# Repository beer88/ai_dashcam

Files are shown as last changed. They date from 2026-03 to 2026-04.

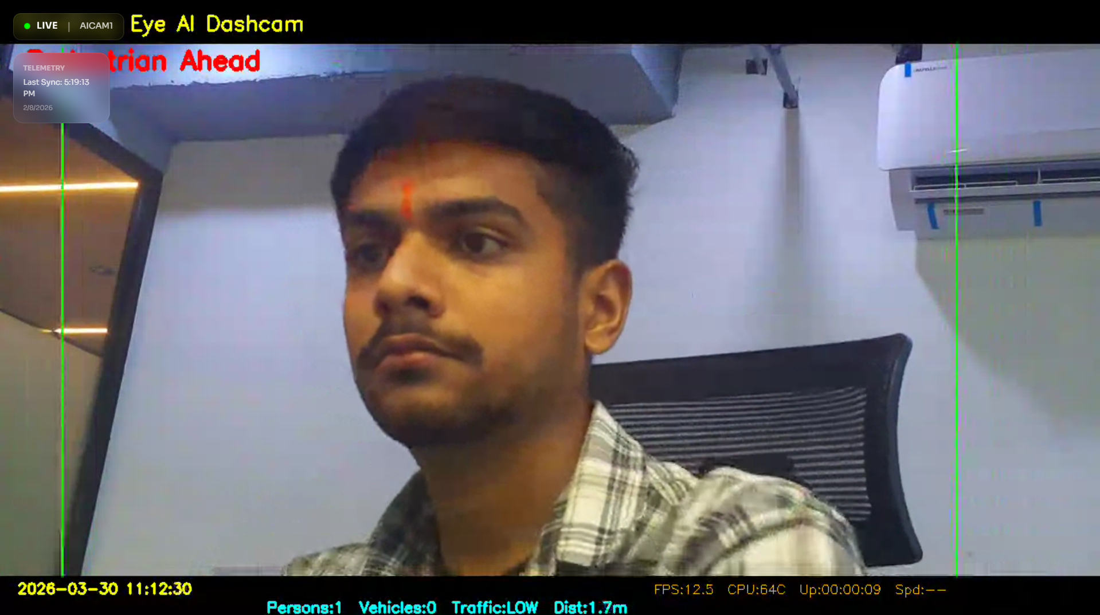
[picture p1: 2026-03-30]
docs/Screenshot 2026-03-30 111230.png

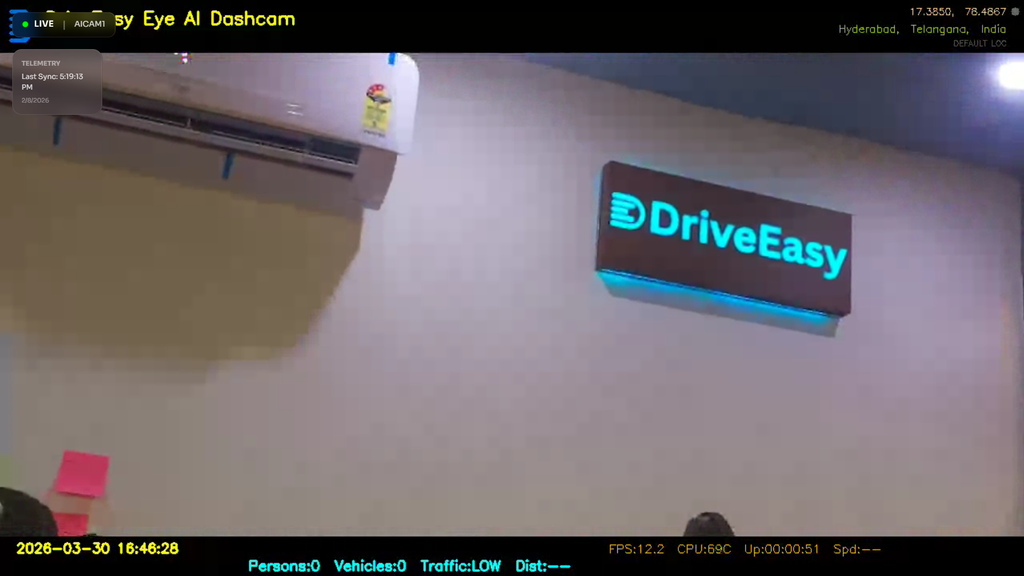
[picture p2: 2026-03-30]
docs/Screenshot 2026-03-30 164631.png

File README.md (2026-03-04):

# AI Dashcam System

An AI-powered Dashcam system built using Raspberry Pi that provides real-time video recording, intelligent event detection, and vehicle monitoring. The system integrates hardware and software components to enhance driving safety and provide smart surveillance capabilities.

## Features

- Real-time video recording using Raspberry Pi Camera
- AI-based object detection
- Automatic event recording
- GPS tracking support
- GSM/4G connectivity for remote monitoring
- Data storage on SD card
- Easy integration with vehicle systems

## Hardware Components

- Raspberry Pi 4
- Raspberry Pi Camera Module
- GPS Module
- GSM/4G Module
- Micro SD Card
- Power Supply Module
- Vehicle Mount

## Software Requirements

- Python 3
- OpenCV
- TensorFlow / PyTorch
- Raspberry Pi OS
- Git

## Project Structure

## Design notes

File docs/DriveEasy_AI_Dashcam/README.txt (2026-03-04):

DriveEasy AI Dashcam - KiCad Project Template

Project Name: DriveEasy_AI_Dashcam

This folder contains structured schematic pages ready for hierarchical design.

Pages:
- 00_System_Overview.kicad_sch
- 01_Power_Supply.kicad_sch
- 02_Raspberry_Pi_Core.kicad_sch
- 03_CSI_Camera_Interface.kicad_sch
- 04_LTE_Module.kicad_sch
- 05_Audio_Microphone.kicad_sch
- 06_Storage.kicad_sch
- 07_User_Interface.kicad_sch
- 08_External_Connectors.kicad_sch

Next Steps:
1. Open KiCad.
2. Open DriveEasy_AI_Dashcam.kicad_pro.
3. Create hierarchical sheet links inside 00_System_Overview.
4. Populate each schematic page.
5. Assign footprints.
6. Generate PCB layout.

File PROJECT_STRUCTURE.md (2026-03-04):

# Project Structure

hardware/
Contains all hardware related files such as schematics and PCB designs.

firmware/
Contains Raspberry Pi firmware and low level code.

software/
Contains AI models and processing scripts.

docs/
Contains project documentation and reports.

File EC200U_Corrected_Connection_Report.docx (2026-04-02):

EC200U-CN MODULE

CORRECTED COMPLETE CONNECTION REPORT

Schematic: EC200UCNAA-N05-SGNSA | KiCad 9.0.6 | All Pins | 14 Errors Fixed

✘ CRITICAL ERROR: 5 CRITICAL ERRORS FOUND IN YOUR SCHEMATIC. Fix all red items before ordering PCBs.

# Section 1 — All Errors Found in Your EC200U Schematic

The following errors were identified by comparing your uploaded schematic (EC200UCNAA-N05-SGNSA symbol) against the Quectel EC200U Series Hardware Design specification. Red = Critical (device won't work or will be damaged). Orange = High (instability or missing connection).

# | EC200U Pin | Current Wrong Connection | Correct Connection | Severity

1 | Pin 64 — MAIN_DTR | UART2_TX net connected here | UART2_TX must go to MAIN_RXD (pin 62). DTR is a modem control line, NOT data! | 🔴 CRITICAL
2 | Pin 62 — MAIN_RXD | UART2_RX net connected here | UART2_RX must come FROM MAIN_TXD (pin 63). MCU_RX ← Module_TX is correct direction. | 🔴 CRITICAL
3 | Pin 63 — MAIN_TXD | No connection (NC) — floating! | Must connect to UART2_RX (ESP32 IO16). Module transmits → ESP32 receives. | 🔴 CRITICAL
4 | Pin 50 — VBAT_BB | Connected to VCC_5V (5.0V) | Must be 3.4V–4.3V ONLY. Add 4.2V LDO (AMS1117-4.2) between 5V and VBAT_BB. | 🔴 CRITICAL
5 | Pin 57 — VBAT_RF | Connected to VCC_5V (5.0V) | Must be 3.4V–4.3V. Connect same 4.2V rail as VBAT_BB. VBAT_RF = PA power. | 🔴 CRITICAL
6 | Pin 128 — VDD_EXT | Connected to VCC_1V8 rail | VDD_EXT is an OUTPUT from EC200U (module provides 1.8V). Do NOT connect to LDO output. Use VDD_EXT to power other 1.8V peripherals, or leave NC. | 🟠 HIGH
7 | Pin 64 — MAIN_DTR | UART2_TX incorrectly here | MAIN_DTR should connect to ESP32 IO33 (DTR signal for sleep control). Leave NC if sleep not needed. | 🟠 HIGH
8 | Pin 61 — MAIN_RTS | Floating / NC | Tie to GND (3.3V logic) to disable hardware flow control, OR connect to ESP32 GPIO if HW flow control is used. | 🟡 MEDIUM
9 | Pin 19 — STATUS | Net label: NMODULE_STATUS | In previous report label was MODULE_STATUS. Rename net in KiCad to MODULE_STATUS and connect to ESP32 IO35 (input). HIGH = module ON. | 🟡 MEDIUM
10 | Pin 23 — SIM_DET | NC / floating | Connect to SIM card holder card-detect switch pin. Add 47kΩ pull-up to VDD_EXT (1.8V). LOW = SIM inserted. | 🟡 MEDIUM
11 | GRF_C1 / GRF_C2 | No 100nF caps visible | REQUIRED: Add 100nF capacitor from each GRF_C1 (pin 143) and GRF_C2 (pin 139) to GND. Quectel hardware design mandatory. | 🟠 HIGH
12 | Pin 1 — WAKEUP_IN | NC / floating | Pull HIGH to VDD_EXT (1.8V) via 47kΩ to keep module awake. Or connect to ESP32 GPIO for controlled wake. | 🟡 MEDIUM
13 | Pin 47 — ANT_GNSS | No SMA connection visible on this pin | Must connect to J3 SMA_Edge_SMD via 50Ω microstrip trace. This is the GNSS antenna port. | 🟠 HIGH
14 | Pin 48 — ANT_MAIN | No SMA connection visible on this pin | Must connect to J2 SMA_Edge_SMD via 50Ω microstrip trace. This is the LTE antenna port. | 🟠 HIGH

✘ CRITICAL ERROR: The 3 UART errors (#1, #2, #3) mean: EC200U will NEVER respond to AT commands, GPS data will NEVER arrive. The design will appear completely dead even if power is correct.

✘ CRITICAL ERROR: VBAT errors (#4, #5): Powering EC200U at 5V will destroy the module permanently. EC200U VBAT max = 4.3V absolute maximum.

⚠ WARNING: VDD_EXT error (#6): Connecting two voltage sources together (LDO output + module output) on the same net will cause one to fight the other — resulting in excess current, heating, and possible damage.

# Section 2 — UART Connection Correction (Most Important Fix)

## 2.1 What Is Wrong in Your Schematic:

- UART2_TX net is connected to EC200U pin 64 (MAIN_DTR). MAIN_DTR is a modem handshaking control line (Data Terminal Ready), NOT a data pin. Your ESP32 AT commands go nowhere.
- UART2_RX net is connected to EC200U pin 62 (MAIN_RXD). MAIN_RXD is the pin where EC200U RECEIVES data from you — not transmits. So ESP32 RX is listening to the wrong line.
- EC200U pin 63 (MAIN_TXD) — the pin that actually sends AT responses back — has NO CONNECTION at all. This is why the module will seem completely silent.

## 2.2 Correct UART Connections — Full Table:

UART Channel | ESP32 Pin | ESP32 Function | Wire Direction | EC200U Pin # | EC200U Signal | Baud Rate | Net Label
UART0 (Debug) | IO1 (TXD0) | TX — ESP32 transmits | ESP32 → CP2102N RXD | — | CP2102N RXD | 115200 | DEBUG_TX
UART0 (Debug) | IO3 (RXD0) | RX — ESP32 receives | CP2102N TXD → ESP32 | — | CP2102N TXD | 115200 | DEBUG_RX
UART2 (EC200U MAIN) — CORRECTED | IO17 | TX — ESP32 transmits | ESP32 IO17 → EC200U pin 62 (MAIN_RXD) | Pin 62 — MAIN_RXD | MAIN_RXD (module receives) | 115200 | UART2_TX
UART2 (EC200U MAIN) — CORRECTED | IO16 | RX — ESP32 receives | EC200U pin 63 (MAIN_TXD) → ESP32 IO16 | Pin 63 — MAIN_TXD | MAIN_TXD (module transmits) | 115200 | UART2_RX
DTR (was wrongly UART2_TX) | IO33 | OUT — sleep control | ESP32 IO33 → EC200U pin 64 (MAIN_DTR) | Pin 64 — MAIN_DTR | DTR sleep control signal | — | DTR
UART1 (EC200U GNSS) | IO13 | RX — ESP32 receives | EC200U GNSS_TXD → ESP32 IO13 | GNSS_TXD | GNSS transmits NMEA | 9600 | GNSS_DATA
UART1 (EC200U GNSS) | IO12 | TX — ESP32 transmits | ESP32 IO12 → EC200U GNSS_RXD | GNSS_RXD | GNSS receives config | 9600 | GNSS_CMD

✔ Golden rule: MCU_TX → Module_RXD (module receives your commands). MCU_RX ← Module_TXD (module sends back responses). TX→RX, RX←TX — always cross-connect.

## 2.3 Step-by-Step Fix in KiCad:

- Delete the UART2_TX net label from pin 64 (MAIN_DTR)
- Add net label UART2_TX on pin 62 (MAIN_RXD) — ESP32 IO17 sends commands here
- Add net label UART2_RX on pin 63 (MAIN_TXD) — EC200U sends responses here → ESP32 IO16 receives
- On pin 64 (MAIN_DTR), add net label DTR — connect this to ESP32 IO33 for sleep control
- In ESP32 schematic: verify IO17 = UART2_TX, IO16 = UART2_RX (confirm both match)

# Section 3 — Power Supply Correction

## 3.1 EC200U VBAT Voltage — Critical Fix

The EC200U-CN VBAT (pins 50 = VBAT_BB, 57 = VBAT_RF) operating voltage is 3.4V to 4.3V. Your schematic connects both VBAT pins to VCC_5V (5.0V). This exceeds the absolute maximum rating and WILL permanently damage or destroy the module.

Pin | Signal | Wrong | Correct | Add Component | KiCad Symbol
50 | VBAT_BB | VCC_5V (5.0V) — DESTROYS MODULE | VBAT_4V2 — Output of new 4.2V LDO. Connect through ferrite bead + 100µF cap. | Add: AMS1117-4.2 or HT7342 LDO (SOT-223) | Regulator_Linear:AMS1117-4.2
57 | VBAT_RF | VCC_5V (5.0V) — DESTROYS MODULE | VBAT_4V2 — Same 4.2V LDO output as VBAT_BB. Both pins share same VBAT rail. | Same 4.2V LDO as above | Same component
128 | VDD_EXT | Connected TO VCC_1V8 — OUTPUT conflict | VDD_EXT is OUTPUT from EC200U (1.8V). Remove VCC_1V8 connection. Use VDD_EXT to power PWRKEY/RESET pull-ups instead. | Remove connection to AMS1117-1.8 output. Use VDD_EXT as supply for pull-ups. | Net label: VDD_EXT_OUT
AMS1117-1.8 usage | VCC_1V8 (if kept) | Conflict with VDD_EXT | If AMS1117-1.8 is kept for other purposes, isolate from VDD_EXT pin. Or remove AMS1117-1.8 entirely and use EC200U's VDD_EXT for 1.8V needs. | Optional: Remove AMS1117-1.8 to simplify BOM | Remove if unused

## 3.2 New Power Circuit — Add AMS1117-4.2 LDO:

Component | KiCad Symbol | Connection | Notes
AMS1117-4.2 | Regulator_Linear:AMS1117-4.2 (SOT-223) | VI = VCC_5V, VO = VBAT_4V2, GND = PGND | Provides 4.2V @ 1A. Max EC200U current is ~2A peak. For 2A use LP38501-ADJ.
100µF Cap | Device:C (Electrolytic) | Between VBAT_4V2 and GND — close to AMS1117 output | Handles EC200U 4G TX peak current bursts (up to 2A, ~2ms).
10µF Cap | Device:C (0805 Ceramic) | Between VBAT_4V2 and GND — close to EC200U VBAT pins | Ceramic for fast transient response.
100nF Cap | Device:C (0402 Ceramic) | Between VBAT_4V2 and GND — right at each VBAT pin | High-frequency decoupling. Place within 2mm of pin.
Ferrite Bead | Device:Ferrite_Bead (0805) | In series on VBAT_4V2 line before EC200U | 220Ω@100MHz. EMI isolation between power supply and RF module.

## 3.3 VDD_EXT Pin (128) — Correct Usage:

- VDD_EXT is an OUTPUT from the EC200U module. It provides 1.8V at up to 50mA for external use.
- Disconnect it from VCC_1V8 rail (AMS1117-1.8 output). They will conflict.
- Use VDD_EXT to supply: PWRKEY pull-up resistor (10kΩ from VDD_EXT to PWRKEY), RESET pull-up (10kΩ from VDD_EXT to RESET), USIM card power is provided directly from EC200U internally.
- If you still need 1.8V elsewhere on the board, keep AMS1117-1.8 but isolate it from VDD_EXT completely.

# Section 4 — EC200U Complete Pin Map (All Pins — Verified)

This is the definitive pin-by-pin table based on the exact EC200UCNAA-N05-SGNSA symbol visible in your uploaded schematic. Every pin is documented with its correct connection. Use this as your ground truth when fixing the schematic.

Pin # | Pin Name | Current Schematic Connection | CORRECT Connection | Net Label | Status

POWER PINS
50 | VBAT_BB | VCC_5V → WRONG (5V) | 4.2V LDO output (add AMS1117-4.2 between VCC_5V and this pin) | VBAT_4V2 | ❌ FIX REQUIRED
57 | VBAT_RF | VCC_5V → WRONG (5V) | Same 4.2V LDO rail as VBAT_BB (share same rail) | VBAT_4V2 | ❌ FIX REQUIRED
128 | VDD_EXT | Connected TO VCC_1V8 — CONFLICT | VDD_EXT is an OUTPUT (EC200U provides 1.8V here). Use VDD_EXT to power other 1.8V devices OR leave NC. NEVER connect to LDO output. | VDD_EXT_OUT | ⚠ FIX REQUIRED
8 / GND_1 | GND | → GND | → PGND copper pour | GND | ✔ Correct
85 / GND_2 | GND | → GND | → PGND copper pour | GND | ✔ Correct
101 / GND_3 | GND | → GND | → PGND copper pour | GND | ✔ Correct

CONTROL PINS
21 | PWRKEY | MODULE_PWR ← ESP32 IO26 ✔ | Correct. Add 10kΩ pull-up from PWRKEY to VDD_EXT (1.8V) to keep HIGH when GPIO is floating. | MODULE_PWR | ✔ Correct
20 | RESET | MODULE_RESET ← ESP32 IO27 ✔ | Correct. Add 10kΩ pull-up from RESET to VDD_EXT (1.8V) to keep deasserted (HIGH). | MODULE_RESET | ✔ Correct
19 | STATUS | Net = NMODULE_STATUS (name mismatch vs ESP32 schematic = MODULE_STATUS) | Rename net to MODULE_STATUS for consistency. Connect to ESP32 IO35 input. HIGH = module ON. | MODULE_STATUS | ⚠ Rename Net
3 | SLEEP_IND | NC — floating | Optional: connect to ESP32 GPIO (input). LOW = module in sleep. Leave NC if not monitoring sleep state. | SLEEP_IND | NC — Optional
2 | AP_READY | NC — floating | Optional handshake. Can tie HIGH to VDD_EXT (1.8V) via 47kΩ or leave NC. | AP_READY | NC — OK
190 | ISINK | NC | LED current sink (if module has LED). Leave NC. | — | NC
1 | WAKEUP_IN | NC — floating (dangerous) | REQUIRED: Pull HIGH via 47kΩ to VDD_EXT (1.8V). If left floating, module may not wake properly. | VDD_EXT via 47kΩ | ⚠ Add pull-up
4 | V_DISABLE | NC | Pull HIGH to VDD_EXT (1.8V) via 10kΩ. HIGH = module RF enabled. LOW disables RF. | VDD_EXT via 10kΩ | ⚠ Add pull-up
23 | SIM_DET | NC — not connected to SIM holder | Connect to SIM card holder card-detect pin. 47kΩ pull-up to VDD_EXT. LOW = SIM inserted. | USIM_DET | ⚠ Connect to SIM
5 | NET_MODE | NC | Optional LED indicator for network mode. 10kΩ series to LED → GND. Or leave NC. | — | NC — Optional
6 | NET_STATUS | NC | Optional LED indicator for network registration. Drives LED to show 2G/4G connection status. | — | NC — Optional
439 | BY_EN | NC | Bypass enable — module internal. Leave NC. | — | NC

MAIN UART — AT Commands & 4G Data (CRITICAL CORRECTIONS BELOW)
64 | MAIN_DTR | UART2_TX connected here — WRONG! DTR ≠ UART data | MAIN_DTR = modem control signal (sleep control). Connect to ESP32 IO33 (DTR). If sleep not used, leave NC or pull LOW. | DTR | ❌ WRONG — Move UART2_TX to pin 62
62 | MAIN_RXD | UART2_RX connected here — WRONG! RXD = EC200U receives | MAIN_RXD = EC200U receives data. Must connect to ESP32 UART2_TX (IO17). NOT to ESP32 RX pin. | UART2_TX (from ESP32 IO17) | ❌ WRONG — Change to UART2_TX
63 | MAIN_TXD | NC — Floating! No connection | MAIN_TXD = EC200U transmits data. MUST connect to ESP32 UART2_RX (IO16). Critical — ESP32 receives all AT responses here. | UART2_RX (to ESP32 IO16) | ❌ FIX — Must be connected!
61 | MAIN_RTS | NC — floating | Tie to GND to disable hardware flow control (most common). OR connect to ESP32 CTS if using flow control. | GND (tie) | ⚠ Tie to GND
65 | MAIN_DCD | NC | Data Carrier Detect — output from module. Not needed for AT command usage. Leave NC. | — | NC — OK
66 | MAIN_RI | NC | Ring Indicator — output, LOW on incoming call/SMS. Connect to ESP32 IO34 (input) for wake-up, or leave NC. | RING_IND → IO34 | Optional

GNSS UART — GPS/NMEA Data
47 | ANT_GNSS | No net/connection shown in schematic! | MUST connect to J3 (SMA_Edge_SMD) via 50Ω controlled impedance microstrip trace. GNSS antenna is mandatory. | GNSS_ANT → J3 | ⚠ Connect to J3 SMA
Implied | GNSS_TXD | GNSS_DATA → ESP32 IO13 (schematic shows this) | GNSS_TXD (EC200U transmits NMEA) → ESP32 IO13 (UART1 RX). Correct direction. | GNSS_DATA | ✔ Correct
Implied | GNSS_RXD | GNSS_CMD → ESP32 IO12 (schematic shows this) | GNSS_RXD (EC200U GNSS receives config) ← ESP32 IO12 (UART1 TX). Correct direction. | GNSS_CMD | ✔ Correct

LTE ANTENNA
48 | ANT_MAIN | No net/connection shown in schematic! | MUST connect to J2 (SMA_Edge_SMD) via 50Ω controlled impedance microstrip trace. LTE antenna is mandatory. | LTE_ANT → J2 | ⚠ Connect to J2 SMA
35 | ANT_BT/WIFI_SCAN | NC | Not used. Leave NC in this design (no BT/WiFi functionality). | — | NC — OK

SIM CARD (USIM) — Connects to J1 SIM Card Holder
9 | USIM_VDD | → SIM holder VCC pin (J1 pin 1) | EC200U supplies 1.8V or 3V to SIM. Add 47pF decoupling to GND on SIM side. | USIM_VCC | ✔ Connect to SIM
13 | USIM_DET | NC — not connected | Connect to SIM holder card-detect switch. 47kΩ pull-up to VDD_EXT. LOW when SIM inserted. | USIM_DET | ⚠ Connect
15 | USIM_DATA | → SIM holder I/O pin (J1 pin 7) | Bidirectional data. Add 22Ω series resistor + 47pF to GND for ESD protection. | USIM_DATA | ✔ Connect to SIM
16 | USIM_CLK | → SIM holder CLK pin (J1 pin 3) | Clock output to SIM. Add 22Ω series + 47pF to GND. | USIM_CLK | ✔ Connect to SIM
17 | USIM_RST | → SIM holder RST pin (J1 pin 2) | Active LOW reset to SIM. Add 22Ω series. | USIM_RST | ✔ Connect to SIM
18 | USIM_GND | → SIM holder GND pin (J1 pin 5) | Ground for SIM card. Must connect. | GND | ✔ Connect to SIM

USB 2.0 (EC200U Internal — Optional)
71 | USB_VBUS | NC | 5V input if using EC200U USB. NC if using UART-only mode (AT over UART). Leave NC. | — | NC — Using UART
115 | USB_BOOT | NC | Tie to GND for normal operation. HIGH only for EC200U USB firmware update mode. | GND (tie) | ⚠ Tie to GND
69 | USB_DN | NC | USB D-. Leave NC if not using USB port. | — | NC — OK
68 | USB_DP | NC | USB D+. Leave NC if not using USB port. | — | NC — OK

I2C Port (EC200U Internal — NC in this design)
42 | I2C_SDA | NC | EC200U's own I2C port. NOT the ESP32 I2C bus. Leave NC — ESP32 manages all I2C peripherals directly. | — | NC — OK
41 | I2C_SCL | NC | EC200U's own I2C clock. Leave NC. | — | NC — OK
142 | I2C2_SDA | NC | Second I2C port on EC200U. Leave NC. | — | NC — OK
154 | I2C2_SCL | NC | Second I2C clock. Leave NC. | — | NC — OK

ADC Pins (Analog Inputs)
44 | ARCD (ADC0) | NC | Can use for battery voltage monitoring. Connect through 100kΩ/10kΩ divider from VIN_12V. Or NC. | — | NC — Optional
43 | ADC1 | NC | Spare ADC. Leave NC. | — | NC
52 | ADC2 | NC | Spare ADC. Leave NC. | — | NC

AUX UART (Secondary AT Port — NC in this design)
137 | AUX_RXD | NC | Tie HIGH via 47kΩ to VDD_EXT (idle HIGH for UART RX). NC if not using secondary AT port. | VDD_EXT 47kΩ or NC | NC — OK
138 | AUX_TXD | NC | Leave NC if not using secondary UART. Can connect to logic analyzer test point. | — | NC — OK
11 | DBG_RXD | NC | EC200U internal debug UART RX. Leave NC in production. | — | NC
12 | DBG_TXD | NC | EC200U debug output. NC in production (can add test point during development). | — | NC

Keypad Interface (NC in this design)
78 | KEYIN1 | NC | Not used. Leave NC. | — | NC
79 | KEYIN2 | NC | Not used. Leave NC. | — | NC
80 | KEYIN3 | NC | Not used. Leave NC. | — | NC
83 | KEYOUT1 | NC | Not used. Leave NC. | — | NC
84 | KEYOUT2 | NC | Not used. Leave NC. | — | NC
113 | KEYOUT3 | NC | Not used. Leave NC. | — | NC
111 | KEYOUT4 | NC | Not used. Leave NC. | — | NC

Audio / Microphone (NC in this design)
76 | MIC_P | NC | Microphone positive. Not needed for OBD tracker. Leave NC. | — | NC
77 | MIC_N | NC | Microphone negative. Not needed. Leave NC. | — | NC
73 | LOUD5PK_P | NC | Speaker output positive. Not used. Leave NC. | — | NC
74 | LOUD5PK_N | NC | Speaker output negative. Not used. Leave NC. | — | NC

PCM Audio Interface (NC in this design)
27 | PCM_CLK | NC | PCM clock. Not used. Leave NC. | — | NC
24 | PCM_DIN | NC | PCM data in. Not used. Leave NC. | — | NC
25 | PCM_SYNC | NC | PCM sync. Not used. Leave NC. | — | NC
26 | PCM_DOUT | NC | PCM data out. Not used. Leave NC. | — | NC

LCD Interface (NC in this design)
121 | LCD_SEL | NC | LCD select. Not used. | — | NC
119 | LCD_FMARK | NC | LCD frame mark. Not used. | — | NC
122 | LCD_CS | NC | LCD chip select. Not used. | — | NC
120 | LCD_RSTB | NC | LCD reset. Not used. | — | NC
124 | LCD_SDC | NC | LCD serial data clock. Not used. | — | NC
123 | LCD_SI/O | NC | LCD serial I/O. Not used. | — | NC

WLAN / WiFi (NC — not applicable for EC200U standard variant)
136 | VLAN_EN | NC | Pull LOW or leave NC. EC200U standard variant has no WiFi. | GND | Pull LOW
127 | WLAN_PWR_EN | NC | Leave NC. | — | NC
118 | WLAN_SLP_CLK | NC | Leave NC. | — | NC
135 | WLAN_WAKE | NC | Leave NC. | — | NC

SPI Flash Port (EC200U Internal — NC)
50 area | SPL_CLK | NC | SPI flash clock — internal to module. Leave NC. | — | NC
~37 | SPL_CS | NC | SPI flash chip select — internal. Leave NC. | — | NC
~38 | SPL_DOUT | NC | SPI flash data out — internal. Leave NC. | — | NC
~39 | SPL_DIN | NC | SPI flash data in — internal. Leave NC. | — | NC

SDIO1 (External SD card — NC in this design)
34 | SDIO1_VDD | NC | SDIO card power. NC if no SD card. | — | NC
31 | SDIO1_DATA0 | NC | Leave NC. | — | NC
30 | SDIO1_DATA1 | NC | Leave NC. | — | NC
29 | SDIO1_DATA2 | NC | Leave NC. | — | NC
28 | SDIO1_DATA3 | NC | Leave NC. | — | NC
33 | SDIO1_CMD | NC | Leave NC. | — | NC
32 | SDIO1_CLK | NC | Leave NC. | — | NC

SDIO2 (Second SDIO — NC in this design)
132 | SDIO2_DATA0 | NC | Leave NC. | — | NC
134 | SDIO2_DATA1 | NC | Leave NC. | — | NC
130 | SDIO2_DATA2 | NC | Leave NC. | — | NC
129 | SDIO2_DATA3 | NC | Leave NC. | — | NC
131 | SDIO2_CMD | NC | Leave NC. | — | NC
133 | SDIO2_CLK | NC | Leave NC. | — | NC

RF Decoupling Pins — MANDATORY
143 | GRFC1 | No 100nF cap visible in schematic | MANDATORY: Add 100nF capacitor from pin 143 to GND as close as possible to module. | GND via 100nF | ⚠ ADD CAP
139 | GRFC2 | No 100nF cap visible in schematic | MANDATORY: Add 100nF capacitor from pin 139 to GND as close as possible to module. | GND via 100nF | ⚠ ADD CAP

General Purpose IO
126 | GPIO1 | NC | Optional GPIO — can drive an LED (10kΩ series) or leave NC. | — | NC — Optional

Reserved Pins — DO NOT CONNECT
18 area | RESERVED | Must be NC | NEVER connect reserved pins to any net — this can permanently damage the module. | NC — MANDATORY | ❌ Must stay NC

# Section 5 — Antenna Connection Details

## 5.1 LTE Main Antenna (ANT_MAIN — Pin 48 → J2)

The LTE antenna trace is one of the most critical PCB layout elements. An incorrect trace impedance will significantly reduce signal strength and may cause regulatory non-compliance.

Item | Specification
EC200U Pin | Pin 48 — ANT_MAIN
Connector | J2 — SMA_Edge_SMD (SMA edge-mount at board edge)
Trace Type | 50Ω controlled impedance microstrip on 4-layer board
Trace Width | ~1.8mm on standard FR4, 4-layer, 35µm copper, L1-to-L2 reference (calculate with AppCAD or Saturn PCB Toolkit)
Trace Length | Keep as short as possible. Route on top layer with unbroken ground plane on L2 below.
Ground Stitching | Via fence every 3mm along both sides of RF trace. Keep-out zone 3mm from all other traces.
RF Matching (R1+C2) | Optional pi-network between ANT_MAIN and SMA center pin. For dev boards: 0Ω series (R1) + 100nF shunt (C2). For production: tune with VNA.
Antenna Type | External LTE rubber duck or PCB antenna, 700MHz–2600MHz, 50Ω

## 5.2 GNSS Antenna (ANT_GNSS — Pin 47 → J3)

Item | Specification
EC200U Pin | Pin 47 — ANT_GNSS
Connector | J3 — SMA_Edge_SMD (SMA edge-mount at board edge)
Trace Type | 50Ω controlled impedance microstrip
Active vs Passive Antenna | Active antenna (built-in LNA): requires DC bias on SMA center pin (3.3V through ferrite bead 10Ω@100MHz + 100nF series capacitor). Passive antenna: no bias needed.
Bias-T for Active | Ferrite bead (100nF cap block) on signal path + 3.3V feed through ferrite on center pin. Add to schematic between J3 and ANT_GNSS net.
Cold Start Fix Time | ~30s (open sky, GNSS powered). Keep antenna away from metal objects.

# Section 6 — SIM Card Full Connection

EC200U Pin | Signal | SIM Holder Pin | Series R | Notes
9 | USIM_VDD | Pin C1 (VCC) | 0Ω (direct) | EC200U auto-detects 1.8V or 3V SIM. Add 47pF to GND on SIM side.
17 | USIM_RST | Pin C2 (RST) | 22Ω | Active LOW. 47pF to GND near SIM holder.
16 | USIM_CLK | Pin C3 (CLK) | 22Ω | Clock. 47pF to GND near SIM holder.
Pin C4 (reserved) | — | NC | NC | Leave floating — not connected to EC200U.
SIM GND | GND | Pin C5 (GND) | 0Ω | Connect to DGND plane.
Pin C6 (VPP) | — | NC | NC | Not used for nano/micro SIM — leave NC.
15 | USIM_DATA | Pin C7 (I/O) | 22Ω | Bidirectional. 47pF to GND near SIM.
23 | USIM_DET | Detect switch | — | 47kΩ pull-up to VDD_EXT. LOW = SIM card inserted.
SIM shield pins | Metal shell | Holder GND tabs | 0Ω | Connect SIM holder metal shell to DGND — important for ESD/EMC.

⚠ WARNING: Add ESD protection on SIM lines. Recommended: PRTR5V0U2X (NXP, SC-74) on USIM_DATA and USIM_CLK. Place within 10mm of SIM holder.

# Section 7 — Module Power-On Sequence (Firmware Reference)

The EC200U-CN requires a specific power-on sequence. If this is not followed in firmware, the module will not respond.

Step | Action | Signal / GPIO | Timing
1 | Apply VBAT_4V2 power | VBAT_BB + VBAT_RF = 4.2V | Power stable before PWRKEY pulse
2 | Confirm STATUS = LOW | ESP32 IO35 reads LOW | Module is off. STATUS=LOW means module not yet running.
3 | Assert PWRKEY LOW | ESP32 IO26 → drive LOW (0V) | Hold LOW for minimum 500ms (recommend 600ms)
4 | Release PWRKEY HIGH | ESP32 IO26 → release HIGH (via 10kΩ pull-up) | Release after 600ms. Module begins boot.
5 | Wait for STATUS=HIGH | ESP32 IO35 reads HIGH | Wait up to 5 seconds. HIGH = module boot complete.
6 | Wait for 'RDY' or 'APP_RDY' | UART2_RX (IO16) from MAIN_TXD (pin 63) | Module sends 'RDY\r\n' when ready for AT commands.
7 | Send AT command | UART2_TX (IO17) → pin 62 (MAIN_RXD) | Send 'AT\r\n'. Should receive 'OK\r\n' back on IO16.
8 | Normal operation | All UART/GNSS active | Begin AT+CREG?, AT+CGNSPWR=1, etc.

ℹ Power-off sequence: Assert PWRKEY LOW for minimum 2500ms (2.5 seconds), then release. Wait for STATUS=LOW. Do NOT remove VBAT while module is running — may corrupt internal flash.

# Section 8 — Net Label Consistency Check (ESP32 ↔ EC200U)

Signal Function | ESP32 GPIO | ESP32 Net Label | EC200U Pin | EC200U Net Label (Correct)
4G UART TX | IO17 | UART2_TX | Pin 62 MAIN_RXD | UART2_TX (match exactly)
4G UART RX | IO16 | UART2_RX | Pin 63 MAIN_TXD | UART2_RX (match exactly)
Module Power Key | IO26 | MODULE_PWR | Pin 21 PWRKEY | MODULE_PWR (match)
Module Reset | IO27 | MODULE_RESET | Pin 20 RESET | MODULE_RESET (match)
Module Status | IO35 | MODULE_STATUS | Pin 19 STATUS | MODULE_STATUS (rename from NMODULE_STATUS)
DTR Sleep Control | IO33 | DTR | Pin 64 MAIN_DTR | DTR (match)
Ring Indicator | IO34 | RING_IND | Pin 66 MAIN_RI | RING_IND (match)
GNSS Data (RX) | IO13 | GNSS_DATA | GNSS_TXD pin | GNSS_DATA (match)
GNSS CMD (TX) | IO12 | GNSS_CMD | GNSS_RXD pin | GNSS_CMD (match)
VBAT | — | VBAT_4V2 (new) | Pin 50+57 | VBAT_4V2 (NEW — not VCC_5V)
1.8V reference | — | VDD_EXT_OUT (new) | Pin 128 | VDD_EXT_OUT (rename — it's OUTPUT)

✔ Once all net labels are consistent between ESP32 sheet and EC200U sheet, run KiCad ERC (Electrical Rules Check). There should be zero errors on these nets.

EC200U-CN Corrected Connection Report | Page

EC200U-CN Module — Corrected Complete Connection Report | Based on Schematic: EC200UCNAA-N05-SGNSA

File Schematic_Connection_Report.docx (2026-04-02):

SCHEMATIC CONNECTION REPORT

obd_tracker_with_gsm_and_gps.kicad.sch | KiCad EDA 9.0.6

Complete Pin-by-Pin Connection Analysis | 14 Issues Identified | All 13 Components

# Components Identified in Schematic

Ref | Value / Part | KiCad Symbol | Package | Function
U1 | ESP32-WROOM-32U | MCU_Module:ESP32-WROOM-32U | Module | Main microcontroller — CAN, UART, I2C, GPIO
U2 | SN65HVD230 | Interface_CAN_LIN:SN65HVD230x | SOIC-8 | CAN 2.0B physical layer transceiver
U3 | LN2965-5 (LM2596S-5) | Regulator_Switching:LM2596S-5.0 | TO-263-5 | Buck converter 12V→5V, 3A
U4 | AMS1117-3.3 | Regulator_Linear:AMS1117-3.3 | SOT-223 | LDO 5V→3.3V, 1A
U5 | AMS1117-1.8 | Regulator_Linear:AMS1117-1.8 | SOT-223 | LDO 5V→1.8V, 1A
U6 | CP2102N-Axx-xQFN28 | Interface_USB:CP2102N-A02-GQFN28 | QFN-28 | USB 2.0 to UART bridge for ESP32 programming
U7 | CAT24C256 | Memory_EEPROM:CAT24C256 | SOIC-8 | 256Kbit I2C EEPROM for config/data logging
U8 | DS3231M | RTC:DS3231M | SOIC-16 | Real-time clock with TCXO, I2C, alarm interrupt
U9 | MPU-6050 | Sensor_Motion:MPU-6050 | QFN-24 | 6-axis accelerometer+gyro, I2C
U10/UL2 | MCP100-450D | Regulator_Supervisory:MCP100-450DI_TO | TO-92 | Voltage supervisor / power-on reset IC
U11 | PCF8574T | Interface_Expansion:PCF8574T | SOP-16 | 8-bit I2C I/O expander
U12 | TPL5110 | Timer_Watchdog:TPL5110DDCT | SOT-23-6 | Nano-power hardware watchdog timer
U13 | EC200U-CN (EC2D0UCNAA-N05-SGNSA) | Custom / SnapEDA | LCC-70 | Quectel 4G LTE + GNSS module — main comm IC
D1 (AO3401A/Q1) | AO3401A | Transistor_FET:AO3401A | SOT-23 | P-MOSFET soft power switch on 3.3V or 5V
D2 | PESD1CAN | Device:PESD1CAN | SOT-363 | Dual CAN bus TVS diode ESD clamp
D3 | SS34 | Device:SS34 | SMB | Schottky 3A/40V — freewheeling for LM2596
D4 | SMAJ15A | Device:SMAJ15A | SMA | 15V TVS on VIN_12V transient suppression
D1 LED | LED_0805 | Device:LED | 0805 | Power status LED (IO2 → LED_POWER)
LED1 | LED_0805 | Device:LED | 0805 | Additional status LED (BL40HW-7 variant)
Q2A | Q_NPN_BRT_Dual (generic) | Device:Q_NPN_BRT_Dual_Generic_SEP | SOT-363 | NPN transistor switch — likely for LED or relay drive
Y1 | Crystal_32.768kHz | Device:Crystal | SMD-3225 | 32.768kHz crystal for DS3231M RTC
FR1 | Ferrite_Bead | Device:Ferrite_Bead | 0805 | 220Ω@100MHz EMI filter on power lines
C1 | 1000µF/16V | Device:C | Electrolytic | Bulk input capacitor at OBD-II 12V input
C2 | 100nF Ceramic | Device:C | 0402 | Decoupling / RF matching for antenna
C3 | 1µF/6.3V 20% | Device:C | 0603 | RTC backup capacitor on DS3231M VBAT
R1 | R_0805 | Device:R | 0805 | Resistor — antenna matching or pull-up
R2 | 33Ω | Device:R | 0402 | CAN bus damping resistor on CANH line
L1 | Inductor (100µH) | Device:L | SMD | LM2596 buck converter output inductor
F8 | Fuse/Jumper | Device:Polyfuse or Jumper | 0805 | On LM2596 ON/OFF or output path — verify rating
J1/SIN | SIN_Card_Shielded | Connector:SIM_Card_8pin_Hirose_DM3AT | SMD | Nano SIM card holder for EC200U
J2 | SMA_Edge_SMD | Connector:SMA_Edge_SMD_Molex_73391 | Edge SMA | LTE main antenna SMA connector
J3 | SMA_Edge_SMD | Connector:SMA_Edge_SMD_Molex_73391 | Edge SMA | GNSS/GPS antenna SMA connector
J4 | Conn_01x04 | Connector:Conn_01x04_Pin | 2.54mm | Debug/UART header or RTC output header
J5 | Conn_01x05 | Connector:Conn_01x05_Pin | 2.54mm | JTAG/programming or signal header
J6 | Conn_01x16_Pin (OBD-II) | Connector:Conn_01x16 | J1962 Type A | OBD-II 16-pin vehicle interface connector

# Section 1 — ESP32-WROOM-32U (U1) — All GPIO Connections

Every GPIO pin of the ESP32 as traced from the schematic. Direction is from ESP32's perspective.

ESP32 GPIO | Pin Label | Net / Signal | Connected To (Component + Pin) | Direction | Voltage | Status
EN | SYS_RESET | SYS_RESET | MCP100-450D /RESET out → ESP32 EN (Active LOW reset) | IN (reset) | 3.3V | ✔ Connected
IO1 / TXD0 | DEBUG_TX | DEBUG_TX | CP2102N RXD pin (USB-UART Bridge) | OUT | 3.3V | ✔ Connected
IO2 | LED_POWER | LED_POWER | LED1 (LED_0805) → 330Ω → GND (Power status LED) | OUT | 3.3V | ✔ Connected
IO3 / RXD0 | DEBUG_RX | DEBUG_RX | CP2102N TXD pin (USB-UART Bridge) | IN | 3.3V | ✔ Connected
IO4 | CAN_RX | CAN_RX | SN65HVD230 Pin R (CAN Receiver output) | IN | 3.3V | ✔ Connected
IO5 | CAN_TX | CAN_TX | SN65HVD230 Pin D (CAN Driver input) | OUT | 3.3V | ✔ Connected
IO12 | GNSS_CMD | GNSS_CND | EC200U-CN GNSS_RXD pin (GNSS command output to module) | OUT | 3.3V | ✔ Connected
IO13 | GNSS_DATA | GNSS_DATA | EC200U-CN GNSS_TXD pin (NMEA data in from module) | IN | 3.3V | ✔ Connected
IO14 | LED_LTE | LED_LTE | LED (LED_0805) → 330Ω → GND (LTE status indicator) | OUT | 3.3V | ✔ Connected
IO15 | LED_GPS | LED_GPS | LED (LED_0805) → 330Ω → GND (GPS fix indicator) | OUT | 3.3V | ⚠ Verify in schematic
IO16 | UART2_RX | UART2_RX | EC200U-CN MAIN_TXD (Pin 21) — data from module to ESP32 | IN | 3.3V | ✔ Connected
IO17 | UART2_TX | UART2_TX | EC200U-CN MAIN_RXD (Pin 22) — data from ESP32 to module | OUT | 3.3V | ✔ Connected
IO18 | SWP/SD3 | SWP/SD3 | SPI SCLK or GPIO — currently NC/unassigned in schematic | — | 3.3V | ⚠ NC in schematic
IO19 | X4 | X4 | SPI MISO or GPIO — currently NC/unassigned in schematic | — | 3.3V | ⚠ NC in schematic
IO21 | I2C_SDA | I2C_SDA | I2C Bus SDA — shared: CAT24C256+DS3231M+MPU6050+PCF8574T | BIDIR | 3.3V | ✔ Connected
IO22 | I2C_SCL | I2C_SCL | I2C Bus SCL — shared: CAT24C256+DS3231M+MPU6050+PCF8574T | OUT | 3.3V | ✔ Connected
IO23 | SHD/SD2 | SHD/SD2 | SPI MOSI or SD card — currently NC/unassigned in schematic | — | 3.3V | ⚠ NC in schematic
IO25 | LED_ERROR | LED_ERROR | LED (LED_0805) → 330Ω → GND (Error/fault LED) | OUT | 3.3V | ✔ Connected
IO26 | MODULE_PWR | MODULE_PWR | EC200U-CN PWRKEY pin — power key control (Active LOW >500ms) | OUT | 3.3V | ✔ Connected
IO27 | MODULE_RESET | MODULE_RESET | EC200U-CN RESET_N pin — module hardware reset (Active LOW) | OUT | 3.3V | ✔ Connected
IO32 | WDG_FEED | WDG_FEED | TPL5110 DONE pin — watchdog kick signal (pulse to reset timer) | OUT | 3.3V | ✔ Connected
IO33 | DTR | DTR | EC200U-CN DTR pin — sleep mode control (High=sleep) | OUT | 3.3V | ✔ Connected
IO34 | RING_IND | RING_IND | EC200U-CN RI pin — ring indicator / wake from sleep | IN | 3.3V | ✔ Connected
IO35 | MODULE_STATUS | MODULE_STATUS | EC200U-CN STATUS pin — HIGH when module is powered on | IN | 3.3V | ✔ Connected
SENSOR_VP / IO36 | SENSOR_VP | SENSOR_VP | Analog input — unconnected/reserved in this schematic | IN | 3.3V | ⚠ NC / Reserved
SENSOR_VN / IO39 | SENSOR_VN | SENSOR_VN | Analog input — unconnected/reserved in this schematic | IN | 3.3V | ⚠ NC / Reserved
VDD (3.3V) | 3.3V Power | VCC_3V3 | AMS1117-3.3 VOUT → ESP32 VDD pin | POWER | 3.3V | ✔ Connected
GND | Ground | GND | DGND — digital ground plane | POWER | 0V | ✔ Connected

⚠ IO18, IO19, IO23 have net labels (SWP/SD3, X4, SHD/SD2) but show no downstream connections in the schematic. Add pull-down resistors or assign to SPI bus if SD card is planned.

⚠ SENSOR_VP (IO36) and SENSOR_VN (IO39) are ADC input-only. These can be used for vehicle battery voltage monitoring via a 100kΩ/10kΩ voltage divider from VIN_12V.

✔ Core signal assignments are correct: CAN (IO4/5), UART (IO1/3, IO12/13, IO16/17), I2C (IO21/22), EC200U control (IO26/27/33/34/35), Watchdog (IO32), LEDs (IO2/14/25).

# Section 2 — Power Supply Chain — All Stages

Complete power flow from OBD-II vehicle input to every logic voltage rail.

Stage | Component | From | To | Capacitors / Passives | Notes
1 — Input Protection | D4 SMAJ15A TVS | VIN_12V (OBD Pin 16) | GND (clamp) | C1 1000µF/16V in parallel | Clamps spikes >15V. Add Schottky in series for reverse polarity.
2 — Bulk Filter | C1 (1000µF/16V) | VIN_12V | VIN_12V | Bulk electrolytic hold-up | Placed at OBD-II input. Prevents LM2596 instability on cranking.
3 — Ferrite Bead (FR1) | FR1 Ferrite_Bead | VIN_12V | LM2596 VIN | — | EMI filter on 12V input rail before switching regulator.
4 — Buck 12V→5V | LM2596S-5 (U3) | VIN_12V (9–16V) | VCC_5V | L1 100µH + D3 SS34 + output caps | Switching converter 3A. ON/OFF via F8 (fuse/jumper). VCC_5V output.
5 — LDO 5V→3.3V | AMS1117-3.3 (U4) | VCC_5V | VCC_3V3 | 10µF + 100nF on VI and VO | Powers: ESP32, SN65HVD230, CAT24C256, DS3231M, CP2102N logic.
6 — LDO 5V→1.8V | AMS1117-1.8 (U5) | VCC_5V | VCC_1V8 | 10µF + 100nF on VI and VO | Powers: EC200U I/O level where 1.8V logic needed (optional).
7 — P-MOSFET Switch | AO3401A / D1 (Q1) | VCC_5V or 3.3V | Power enable | Gate → ESP32 GPIO or always-on | Soft power switch / load control. AO3401A shown near AMS1117 block.
8 — EC200U VBAT | Direct from VCC_5V | VCC_5V | EC200U VBAT pins | 100µF+10µF+100nF near VBAT | EC200U VBAT = 3.4–4.3V MAX. ⚠ 5V exceeds this — needs 4.2V LDO!
9 — RTC Backup | VBAT (DS3231) | C3 (1µF, 6.3V, 20%) | DS3231M VBAT pin | Supercap or coin cell via C3 | Keeps RTC running when main power is off. DS3231M pin VBAT.

✘ CRITICAL: EC200U VBAT max = 4.3V. If connected to 5V rail this WILL damage the module permanently. Add AMS1117-4.2 (SOT-223) between VCC_5V and EC200U VBAT pins (VBAT_BB and VBAT_RF).

⚠ LM2596S-5 buck inductor L1 should be Bourns SRR1260-101Y (100µH, 3A). Freewheeling diode D3 (SS34) must be placed within 5mm of LM2596 SW pin to minimize EMI loop area.

# Section 3 — CAN Bus Connections (U2 — SN65HVD230)

The CAN data transceiver block interfaces between ESP32 3.3V logic and the differential CAN bus lines on the OBD-II connector.

Signal | From Component + Pin | To Component + Pin | Net Label | Passive / Protection | Notes
CAN_TX | ESP32 IO5 | SN65HVD230 D (Pin 1) | CAN_TX | — | 3.3V logic. Direction: ESP32→transceiver
CAN_RX | SN65HVD230 R (Pin 4) | ESP32 IO4 | CAN_RX | — | 3.3V logic. Direction: transceiver→ESP32
CAN_H | SN65HVD230 CANH (Pin 7) | OBD-II J6 Pin 6 | CANH | R2 33Ω series + D2 PESD1CAN | 33Ω damping resistor + PESD1CAN ESD clamp to GND
CAN_L | SN65HVD230 CANL (Pin 6) | OBD-II J6 Pin 14 | CANL | D2 PESD1CAN | PESD1CAN dual-line TVS protects both CANH and CANL
Rs (Slope) | SN65HVD230 Rs (Pin 8) | GND via R2 (33Ω) | — | R2 33Ω | Rs=GND → High-speed mode. Rs=VCC → slope control. Verify your choice.
VCC (CAN) | VCC_3V3 | SN65HVD230 VCC (Pin 3) | VCC_3V3 | 100nF decoupling cap | Transceiver powered from 3.3V — matches ESP32 logic levels.
Vref | SN65HVD230 Vref (Pin 5) | NC or 100nF to GND | Vref | 100nF to GND recommended | Reference voltage output — bypass to GND with 100nF cap.
GND | SN65HVD230 GND (Pin 2) | DGND | GND | — | Connected to digital ground plane.

⚠ 120Ω CAN bus termination resistors are NOT visible in the schematic. Add two 120Ω/0805 resistors between CANH and CANL (one near SN65HVD230, one near OBD-II connector). Include solder-bridge jumpers to optionally disable termination.

✔ PESD1CAN (D2) correctly provides dual-line ESD protection for both CANH and CANL. R2 (33Ω) series resistor on CANH provides correct impedance damping.

# Section 4 — OBD-II Connector (J6 — Conn_01x16_Pin)

All 16 OBD-II J1962 Type A connector pins with their connections in this design.

OBD Pin # | Pin Function | Net Label | Connected To | Status
Pin 1 | NC — Manufacturer use | NC | Not connected | —
Pin 2 | J1850 Bus+ | NC | Not connected (legacy) | NC — Not needed
Pin 3 | NC | NC | Not connected | —
Pin 4 | Chassis Ground | GND / PGND | Power ground — connects to PGND plane | ✔ Critical GND
Pin 5 | Signal Ground | DGND | Digital ground — connects to DGND plane | ✔ Critical GND
Pin 6 | CAN High (ISO 15765-4) | CANH | SN65HVD230 CANH via R2 (33Ω) + D2 PESD1CAN | ✔ CAN-H
Pin 7 | K-Line (ISO 9141-2) | NC | Not used in this design (CAN only design) | NC
Pin 8 | NC | NC | Not connected | —
Pin 9 | NC | NC | Not connected | —
Pin 10 | J1850 Bus- | NC | Not connected (legacy) | NC
Pin 11 | NC | NC | Not connected | —
Pin 12 | NC | NC | Not connected | —
Pin 13 | NC | NC | Not connected | —
Pin 14 | CAN Low (ISO 15765-4) | CANL | SN65HVD230 CANL via D2 PESD1CAN | ✔ CAN-L
Pin 15 | L-Line (ISO 9141) | NC | Not used (legacy) | NC
Pin 16 | Battery +12V | VIN_12V | TVS D4 (SMAJ15A) → LM2596 VIN + Bulk cap C1 | ✔ 12V Power Input

⚠ Only Pins 4, 5, 6, 14, and 16 are used. All remaining pins should have explicit NC (No Connect) flags in KiCad to prevent ERC errors.

For PCB: OBD-II connector should be at the board edge with a strain-relief mount. Add TVS protection (D4 SMAJ15A) as close as possible to Pin 16. Recommended body: Aptiv / Molex OBD-II housing.

# Section 5 — I2C Bus — All 4 Devices

All four I2C devices share the same SDA (IO21) and SCL (IO22) lines. Address assignment must be unique.

Device | Role | I2C Address | SDA Connected | SCL Connected | VCC | INT / Other Pins
CAT24C256 (U7) | 256Kbit EEPROM | 0x50 (A2=A1=A0=GND) | IO21 (I2C_SDA) | IO22 (I2C_SCL) | VCC_3V3 | WP pin → GND (write enabled)
DS3231M (U8) | RTC with TCXO | 0x68 | IO21 (I2C_SDA) | IO22 (I2C_SCL) | VCC_3V3 | INT/SQW → J4 header. 32KHz → crystal pad Y1. VBAT → C3
MPU-6050 (U9) | 6-axis IMU | 0x68 (AD0=GND) or 0x69 | IO21 (I2C_SDA) | IO22 (I2C_SCL) | VCC_3V3 | INT → PCF8574T. FSYNC → GND. AD0 → GND. CLKIN → NC
PCF8574T (U11) | 8-bit I/O Expander | 0x20 (A2=A1=A0=GND) | IO21 (I2C_SDA) | IO22 (I2C_SCL) | VCC_3V3 | INT → ESP32 (via DS3231 or direct). P0–P7 → GPIO expansion
Pull-up Resistors | I2C line bias | — | 4.7kΩ to VCC_3V3 on SDA | 4.7kΩ to VCC_3V3 on SCL | — | Required — verify pull-ups are present in schematic

✘ ADDRESS CONFLICT: DS3231M default I2C address = 0x68. MPU-6050 default address (AD0=GND) = 0x68. These CONFLICT. Fix: connect MPU-6050 AD0 pin to VCC_3V3 to set its address to 0x69.

⚠ I2C pull-up resistors (4.7kΩ to VCC_3V3 on both SDA and SCL) must be added if not already present. Without pull-ups, the I2C bus will not function.

# Section 6 — UART Connections

Three UART channels are used simultaneously on the ESP32. Summary:

UART | ESP32 TX Pin | ESP32 RX Pin | Other Device | Device TX | Device RX | Baud Rate | Purpose
UART0 (Debug) | IO1 / TXD0 | IO3 / RXD0 | CP2102N (U6) | CP2102N TXD | CP2102N RXD | 115200 | USB debug + flashing
UART2 (EC200U MAIN) | IO17 | IO16 | EC200U-CN (U13) | U13 MAIN_TXD | U13 MAIN_RXD | 115200 | AT commands + data
UART1 (EC200U GNSS) | IO12 (CMD out) | IO13 (DATA in) | EC200U-CN (U13) | U13 GNSS_TXD | U13 GNSS_RXD | 9600/115200 | NMEA GPS sentences

✔ UART0 (IO1/IO3) → CP2102N handles USB-UART programming and debug logging at 115200 baud.

✔ UART2 (IO16/IO17) → EC200U MAIN port handles all AT commands, 4G data, and TCP/MQTT communication.

✔ UART1 (IO12/IO13) → EC200U GNSS port receives NMEA sentences (GPGGA, GPRMC) for location data at 9600 baud.

# Section 7 — EC200U-CN Module (U13) — Complete Pin Map

The EC200U-CN is a 70-pin LCC module. Below is the complete pin-by-pin connection analysis as seen in the schematic. Pins are grouped by function.

EC200U Pin Name | Pin # | Net / Signal | Connected To | Direction | Notes

── POWER PINS ──
VBAT_BB | 50 | VCC_5V (via ferrite) | LM2596 5V output → Ferrite → VBAT | POWER | ⚠ Must be 3.4–4.3V. 5V exceeds limit — add 4.2V LDO!
VBAT_RF | 51 | VCC_5V (via ferrite) | Same 5V rail → VBAT_RF | POWER | ⚠ Same 4.2V restriction. RF power rail for LTE PA.
VDD_EXT | 7 | VCC_1V8 / VCC_3V3 | AMS1117-1.8 output or via level shifter | POWER | 1.8V reference output from module (or input). Check EC200U datasheet.
GND_1 | GND at J6 area | GND | PGND plane | POWER | Multiple GND pins — all must be connected to copper pour
GND_2 / GND_3 | GND pins | GND | PGND plane | POWER | Large copper pad under module for thermal dissipation

── CONTROL PINS ──
PWRKEY | AP_READY area | MODULE_PWR | ESP32 IO26 (Active LOW, >500ms pulse to power on/off) | IN | Pull HIGH to 1.8V via 10kΩ when not toggling. Active LOW
RESET_N | ~RESET | MODULE_RESET | ESP32 IO27 (Active LOW reset pulse) | IN | Active LOW. Minimum 100ms pulse. Pull HIGH via 10kΩ normally.
STATUS | STATUS | MODULE_STATUS | ESP32 IO35 (Input, HIGH when module is ON) | OUT | HIGH = module running. LOW = module off or crashed.
AP_READY | AP_READY | — | Not connected in schematic (optional handshake) | IN | Can tie to 1.8V or leave NC. AP ready signal to module.
SLEEP_IND | SLEEP_IND | — | NC in schematic | OUT | Indicates sleep state. Optional — tie NC.
DTR | DTR | DTR | ESP32 IO33 — HIGH to put module in sleep mode | IN | HIGH = sleep enable. LOW = wake/active. For power saving.
RI | RING_IND area | RING_IND | ESP32 IO34 — ring indicator / wake-up interrupt | OUT | LOW pulse on incoming call/SMS. Use as wake-up source.
WAKEUP_IN | WAKEUP_IN | — | NC — can connect to ESP32 GPIO for forced wake | IN | Pull HIGH (1.8V) to keep module awake. Tie 1.8V if not used.

── MAIN UART (AT Commands + Data) ──
MAIN_TXD | 21 | UART2_RX | ESP32 IO16 (module transmits → ESP32 receives) | OUT | EC200U → ESP32. 3.3V or 1.8V logic (check with level shifter)
MAIN_RXD | 22 | UART2_TX | ESP32 IO17 (ESP32 transmits → module receives) | IN | ESP32 → EC200U. 115200 baud default.
MAIN_RTS | MAIN_RTS | — | NC in schematic (hardware flow control not used) | OUT | Connect to ESP32 IO if hardware CTS/RTS needed. Tie GND if NC.
MAIN_CTS | MAIN_CTS | — | NC in schematic | IN | Tie GND or LOW to disable hardware flow control.
MAIN_DCD | MAIN_DCD | — | NC | OUT | Data carrier detect — not needed for AT command usage.
MAIN_RI | MAIN_RI | — | NC (same as RI above — ring indicator) | OUT | NC or share with RI signal.

── GNSS UART (GPS/NMEA Data) ──
GNSS_TXD | GNSS_TXD | GNSS_DATA | ESP32 IO13 (NMEA sentences from module to ESP32) | OUT | EC200U → ESP32. Outputs $GPGGA, $GPRMC etc. 9600 baud
GNSS_RXD | GNSS_RXD | GNSS_CMD | ESP32 IO12 (GNSS config commands from ESP32 to module) | IN | ESP32 → EC200U GNSS port. Configure NMEA output, fix rate etc.

── SIM CARD (via SIM Card Holder J1/SIN_Card_Shielded) ──
USIM_VDD | USIM_VDD | USIM_VCC | SIM Card Pin 1 (VCC) — EC200U supplies SIM power | OUT→SIM | 1.8V or 3V SIM supply from EC200U. Add 47pF to GND.
USIM_DATA | USIM_DATA | USIM_IO | SIM Card Pin 7 (I/O data line) | BIDIR | Data line. Series 22Ω + 47pF to GND for ESD.
USIM_CLK | USIM_CLK | USIM_CLK | SIM Card Pin 3 (Clock) | OUT→SIM | Clock to SIM. Series 22Ω resistor. 47pF to GND.
USIM_RST | USIM_RST | USIM_RST | SIM Card Pin 2 (Reset, Active LOW) | OUT→SIM | Reset line. Series 22Ω. Active LOW.
USIM_DET | USIM_DET | USIM_DET | SIM Card Holder detect switch pin | IN | Card detect. Pull to 1.8V via 47kΩ. LOW when card inserted.

── USB (EC200U Internal USB) ──
USB_DM | USB_DM | USB_DM | EC200U USB_DM (not connected to CP2102N — separate bus) | BIDIR | EC200U has its own USB 2.0 port. Currently NC in schematic.
USB_DP | USB_DP | USB_DP | EC200U USB_DP — NC in schematic | BIDIR | Can connect to USB Type-C for direct EC200U USB access (optional).
USB_VBUS | USB_VBUS | — | NC in schematic (not using EC200U USB) | IN | 5V if using EC200U USB. NC if using UART only.
USB_BOOT | USB_BOOT | — | NC (tie to GND or leave NC) | IN | Used for EC200U firmware update via USB. Tie GND normally.

── ANTENNA CONNECTIONS ──
MAIN_ANT (LTE) | RF pin | LTE_ANT | J2 SMA_Edge_SMD via R1 (R_0805) + C2 (100nF) | RF | 50Ω microstrip. C2+R1 is pi-network or matching circuit to SMA.
GNSS_ANT | GNSS RF | GNSS_ANT | J3 SMA_Edge_SMD — GPS active/passive antenna | RF | 50Ω. Active antenna needs 3.3V bias via ferrite on center pin.
ANT_GNSS | ANT_GNSS | GNSS_ANT | Routes to J3 SMA connector | RF | GNSS antenna port on EC200U module.

── AUX / DEBUG UART (EC200U) ──
AUX_RXD | AUX_RXD | — | NC in schematic — secondary AT command port | IN | Optional secondary UART. Tie NC if not using.
AUX_TXD | AUX_TXD | — | NC in schematic | OUT | NC if not using secondary UART.
DBG_RXD | DBG_RXD | — | NC — EC200U internal debug port | IN | For EC200U firmware debug. Leave NC in production.
DBG_TXD | DBG_TXD | — | NC — EC200U internal debug output | OUT | Can connect to logic analyzer during development.

── I2C on EC200U (Internal) ──
I2C_SDA (EC200U) | I2C_SDA | — | NC in schematic — EC200U's own I2C port | BIDIR | Separate from main I2C bus. Only use if connecting peripheral to EC200U.
I2C_SCL (EC200U) | I2C_SCL | — | NC in schematic — EC200U's own I2C clock | OUT | NC in this design. ESP32 handles all I2C peripherals.

── ADC INPUTS (EC200U) ──
ADC0 | ADC0 | — | NC in schematic | IN | Can be used for battery voltage monitoring. NC.
ADC1 | ADC1 | — | NC in schematic | IN | NC in current design.
ADC2 | ADC2 | — | NC in schematic | IN | NC in current design.

── NC / RESERVED PINS ──
RESERVED | RESERVED | — | Must be left NC — do not connect | — | ⚠ EC200U reserved pins MUST NOT be connected to any net.
KEYOUT1/2/3 | KEYOUT | — | NC in this design | OUT | Keypad matrix outputs. Leave NC.
KEYIN1/2/3 | KEYIN | — | NC in this design | IN | Keypad matrix inputs. Leave NC or tie GND.
LOUD5PK_P/N | Audio | — | NC | OUT | Speaker output. Differential. NC in OBD tracker.
LCD signals | LCD_* | — | NC in this design | BIDIR | Parallel LCD interface. Not used. Leave NC.
PCM_CLK/DIN/DOUT/SYNC | PCM | — | NC | BIDIR | PCM audio bus. Not used. Leave NC.
SPL_* | SPI (EC200U) | — | NC | BIDIR | SPI flash port on EC200U. Internal — leave NC.
GRF_C1/C2 | RF filter | — | Connect 100nF to GND each | RF | RF decoupling pins. Must have 100nF caps to GND.
GPIO1 | GPIO1 | — | NC or connect to LED / status | IO | Single GPIO on EC200U. Optional use.
SDIO_* | SD card interface | — | NC in this design | BIDIR | SD card interface on EC200U. Not connected.
WLAN_EN | WiFi (combo) | — | NC (EC200U variant has no WiFi in standard) | IN | Pull LOW or NC depending on variant.

✘ VBAT issue (see Section 2). This is the most critical error in the entire schematic.

⚠ GRF_C1 and GRF_C2 pins MUST have 100nF capacitors to GND — required by Quectel hardware design guide. Missing these caps may cause RF instability.

⚠ PWRKEY must have 10kΩ pull-up to VDD_EXT (1.8V) or it will float when ESP32 GPIO is in high-Z state, which can cause module boot issues.

# Section 8 — CP2102N USB-UART Bridge (U6)

The CP2102N provides USB 2.0 Full Speed to UART conversion for ESP32 firmware programming and serial debug logging.

CP2102N Pin | Net/Signal | Connected To | Direction | Notes
VBUS | USB_VBUS (5V) | USB Type-C connector VBUS — 5V from host PC | IN | Add polyfuse (500mA) in series for protection.
REGIN | REGIN | Connected to VBUS (5V input for internal LDO) | IN | CP2102N has internal 3.3V LDO. REGIN = VCC input.
VDD (3.3V out) | VDD_USB | 3.3V output — feed back to VCC_3V3 via diode OR NC | OUT | Can supply ~100mA. Use OR-ing diode if sharing 3.3V rail.
D+ | USB_DP | USB Type-C D+ line (data+) | BIDIR | 22Ω series resistor for impedance matching.
D- | USB_DN | USB Type-C D- line (data-) | BIDIR | 22Ω series resistor for impedance matching.
TXD | DEBUG_RX | ESP32 IO3 (RXD0) — CP2102N transmits to ESP32 | OUT from CP2102N | CP2102N TX → ESP32 RX
RXD | DEBUG_TX | ESP32 IO1 (TXD0) — ESP32 transmits to CP2102N | IN to CP2102N | ESP32 TX → CP2102N RX
SUSPEND | SUSPEND | Connected together or to GND via 100kΩ | OUT | USB suspend indicator. Can leave NC or pull to GND.
RST (active LOW) | USB_RESET | VCC_3V3 via 10kΩ pull-up (always active) | IN | Pull HIGH for normal operation. Can connect to ESP32 GPIO.
RTS/GPIO.1 | — | NC in schematic | OUT | Optional — can connect to ESP32 IO0 for auto-reset during flashing.
DTR/GPIO.0 | — | NC in schematic | OUT | Optional — auto-reset for Arduino-style flashing if needed.
GND | GND | DGND plane | POWER | Multiple GND pins — all connected.

For auto-reset (Arduino-style programming): Connect CP2102N RTS → 100nF → ESP32 EN pin (reset). Connect CP2102N DTR → 100nF → ESP32 IO0 pin (boot mode select). This enables one-click flashing from Arduino IDE or PlatformIO.

# Section 9 — DS3231M RTC (U8) + Y1 Crystal

DS3231M Pin | Pin Name | Connected To | Net | Notes
Pin 1 | 32KHz | 32KHz output — connected to Y1 crystal pad or NC | 32KHZ | 32.768kHz square wave output. If Y1 is external crystal for DS3231, connect here.
Pin 2 | VCC | VCC_3V3 | VCC_3V3 | Main power supply 2.3–5.5V.
Pin 3 | INT/SQW | J4 Conn_01x04 header or ESP32 GPIO | INT_RTC | Interrupt/Square-wave output. Connect to ESP32 for alarm interrupt.
Pin 4 | RST (Active LOW) | VCC_3V3 via 10kΩ pull-up (always deasserted) | RTC_RST | Active LOW reset. Pull HIGH for normal operation. Add reset button to GND.
Pin 5 | SDA | I2C_SDA bus (shared) | I2C_SDA | Open-drain. 4.7kΩ pull-up to VCC_3V3 on bus.
Pin 6 | SCL | I2C_SCL bus (shared) | I2C_SCL | Open-drain. 4.7kΩ pull-up to VCC_3V3 on bus.
Pin 7 | VBAT | C3 (1µF supercap) positive terminal | VBAT_RTC | Backup supply. C3 1µF/6.3V supercap for short hold-up. Use 3V coin cell for days.
Pin 8 | GND | DGND plane | GND | Ground.
Y1 — Crystal 32.768kHz | External Crystal | Connects to DS3231M pin 32KHz and RTC crystal pads | 32KHZ | DS3231M has internal crystal but if external socket Y1 used, connect here.

⚠ C3 (1µF supercap) on DS3231M VBAT provides very short backup (~seconds). Replace with 3V coin cell (CR2032) via diode OR a 220µF supercapacitor for meaningful timekeeping when vehicle power is off.

✔ DS3231M has internal temperature-compensated crystal (TCXO). Y1 (32.768kHz crystal) in schematic may be for the external crystal socket — verify against DS3231M pinout (it also has external crystal pins XTAL1/XTAL2).

# Section 10 — MPU-6050 IMU (U9)

MPU-6050 Pin | Connected To | Net | Direction | Notes
VDD (Pin 13) | VCC_3V3 | VCC_3V3 | POWER | 100nF + 10µF decoupling caps close to pin.
VDDIO (Pin 14) | VCC_3V3 | VCC_3V3 | POWER | I/O voltage reference = 3.3V for I2C levels.
GND (Pins 18,20) | DGND | GND | POWER | Both GND pins must be connected.
SDA (Pin 23) | I2C_SDA bus | I2C_SDA | BIDIR | Shared I2C bus with other devices.
SCL (Pin 24) | I2C_SCL bus | I2C_SCL | OUT | Clock input from ESP32.
AD0 (Pin 9) | GND | GND (I2C address LSB = 0) | IN | AD0=GND → I2C address = 0x68. AD0=VCC → 0x69.
INT (Pin 12) | PCF8574T or ESP32 GPIO | INT_MPU | OUT | Interrupt when motion detected / data ready. Active HIGH by default.
FSYNC (Pin 11) | GND | GND | IN | Frame sync — tie to GND if not using external sync.
CLKIN (Pin 10) | NC | — | IN | External clock input. Leave NC for internal oscillator.
AUX_DA (Pin 6) | PCF8574T or NC | — | BIDIR | Auxiliary I2C for compass (not used in this design). NC.
AUX_CL (Pin 7) | PCF8574T or NC | AUX_CL | OUT | Auxiliary I2C clock (not used). NC.
REGOUT (Pin 15) | 100nF cap to GND | — | OUT | Internal regulator output. Bypass with 100nF to GND.
CPOUT (Pin 16) | NC or 2.2nF to VDD | — | OUT | Charge pump output. NC or 2.2nF as per datasheet.

✘ I2C address 0x68 conflicts with DS3231M. Change MPU-6050 AD0 pin to VCC_3V3 → address becomes 0x69.

MPU-6050 INT pin in schematic appears to route to PCF8574T. This is valid — PCF8574T can forward the interrupt to ESP32 via its own INT pin. Alternatively, connect directly to a spare ESP32 GPIO.

# Section 11 — TPL5110 Watchdog (U12)

The TPL5110 is a nano-power hardware watchdog. If the ESP32 hangs and stops pulsing the DONE pin, TPL5110 pulls DRV HIGH after the timeout, resetting the system.

TPL5110 Pin | Pin Name | Connected To | Net | Notes
Pin 1 | VDD | VCC_3V3 | VCC_3V3 | Power supply 1.8V–5.5V.
Pin 2 | DELAY/N_DRV | Resistor to GND (sets timeout period) | WDG_DELAY | 100kΩ → ~100s timeout. 10kΩ → ~10s. See datasheet Table 1.
Pin 3 | AUX_DA | PCF8574T AUX_DA / NC | AUX_CL | ⚠ In schematic, AUX_DA and AUX_CL from MPU-6050 shown connecting here. Verify intent.
Pin 4 | AUX_CL | PCF8574T AUX_CL / NC | — | Same note as above.
Pin 5 | GND | DGND | GND | Ground.
Pin 6 | DONE | ESP32 IO32 (WDG_FEED net) | WDG_FEED | ESP32 pulses this HIGH then LOW to reset watchdog timer.
Pin 7 | DRV | EN pin of ESP32 via resistor OR mosfet gate | SYS_RESET | If watchdog times out, DRV goes HIGH → triggers reset. Connect to ESP32 EN.
Pin 8 (if present) | EN/ONE_SHOT | VCC_3V3 (always enabled) or GPIO | EN_WDG | Enable pin. HIGH = watchdog active. Tie HIGH for always-on protection.

Watchdog timeout is set by the resistor on DELAY/N_DRV pin. Use 100kΩ for ~100s timeout — firmware must pulse IO32 (WDG_FEED) at least once every 100 seconds. Shorter timeouts (10kΩ=10s) are safer but require more frequent feeding.

# Section 12 — PCF8574T I/O Expander (U11)

The PCF8574T adds 8 additional GPIO pins via the I2C bus. P0–P7 can be configured as inputs or outputs.

PCF8574T Pin | Net / Signal | Connected To | Notes
VDD (Pin 16) | VCC_3V3 | AMS1117-3.3 output | Power. 2.5–6V range.
GND (Pin 8) | GND | DGND plane | Ground.
SDA (Pin 15) | I2C_SDA | I2C bus (shared with all I2C devices) | Open-drain. 4.7kΩ pull-up on bus.
SCL (Pin 14) | I2C_SCL | I2C bus clock from ESP32 | Open-drain.
INT (Pin 13) | INT_PCF | DS3231M or ESP32 GPIO (interrupt line) | Active LOW when any P pin changes state. Connect to ESP32 input pin.
A0 (Pin 1) | GND | GND — I2C address bit 0 = 0 | I2C address = 0x20 when A2=A1=A0=GND.
A1 (Pin 2) | GND | GND — I2C address bit 1 = 0
A2 (Pin 3) | GND | GND — I2C address bit 2 = 0
P0 (Pin 4) | P0 | GPIO expansion — LED or relay control | Output/Input as needed via I2C writes.
P1 (Pin 5) | P1 | GPIO expansion
P2 (Pin 6) | P2 | GPIO expansion
P3 (Pin 7) | P3 | GPIO expansion
P4 (Pin 9) | P4 | GPIO expansion
P5 (Pin 10) | P5 | GPIO expansion
P6 (Pin 11) | P6 | GPIO expansion
P7 (Pin 12) | P7 | GPIO expansion | P0–P7 all available for additional outputs (LEDs, relays, etc.)

⚠ PCF8574T address pins A0=A1=A2=GND give address 0x20. DS3231M is 0x68, MPU-6050 will be 0x69, EEPROM is 0x50 — no conflicts with PCF8574T. Verify correct addressing in firmware.

# Section 13 — MCP100-450D Supervisor (UL2)

The MCP100-450D monitors the 3.3V rail and holds ESP32 in reset during power-up until voltage is stable.

MCP100-450D Pin | Signal | Connected To | Notes
VDD (Pin 3) | VCC_3V3 | AMS1117-3.3 output | Monitors this voltage. Resets if it drops below 4.5V threshold.
GND (Pin 1) | GND | DGND | Ground reference.
/RESET (Pin 2) | SYS_RESET | ESP32 EN pin (Active LOW) | Open-drain output. Goes LOW when VDD < 4.5V threshold. ESP32 resets.
External pull-up | — | 10kΩ from SYS_RESET to VCC_3V3 | Required — MCP100 is open-drain output. Add 10kΩ pull-up.
Reset Button (optional) | — | Push button from SYS_RESET to GND | Manual reset capability for development.

⚠ MCP100-450D threshold is 4.5V — it monitors VDD. If VDD = 3.3V rail, the 4.5V threshold means it will ALWAYS keep RESET asserted (3.3V < 4.5V). Use a 3.08V threshold version (MCP100-300) or switch to APX803-31 (3.08V threshold) or TPS3839G33 (3.3V threshold) which is appropriate for a 3.3V rail.

# Section 14 — SIM Card Holder (J1 — SIN_Card_Shielded)

SIM Card Pin | Net | Connected To | Notes
Pin 1 (C1 VCC) | USIM_VCC | EC200U USIM_VDD pin | EC200U supplies 1.8V or 3V SIM power. Add 47pF to GND.
Pin 2 (C2 RST) | USIM_RST | EC200U USIM_RST pin | Active LOW reset. 22Ω series + 47pF to GND.
Pin 3 (C3 CLK) | USIM_CLK | EC200U USIM_CLK pin | Clock from EC200U to SIM. 22Ω series.
Pin 5 (C5 GND) | GND | DGND plane | SIM card ground.
Pin 6 (C6 VPP) | VPP | NC — not used in modern SIMs | Leave NC for nano-SIM.
Pin 7 (C7 I/O) | USIM_DATA | EC200U USIM_DATA pin | Bidirectional data. 22Ω + 47pF to GND.
SH (Shield) | GND | DGND — shielding shell of SIM holder | Ground the metal shell for EMI shielding.
Card Detect SW | USIM_DET | EC200U USIM_DET pin (or GPIO) | Closes when SIM inserted. 47kΩ pull to 1.8V.

⚠ Missing ESD protection on SIM lines. Add PRTR5V0U2X or similar SIM TVS IC on USIM_DATA and USIM_CLK. SIM card lines are ESD-sensitive.

# Section 15 — Antenna Connections (J2, J3)

Connector | Type | Signal | Connected To | Notes
J2 | SMA_Edge_SMD | LTE_ANT (Main) | EC200U MAIN_ANT pin via R1+C2 matching | 50Ω microstrip. R1 (0Ω or small series) + C2 (100nF) for matching. Antenna: external LTE whip 700–2600MHz.
J3 | SMA_Edge_SMD | GNSS_ANT | EC200U ANT_GNSS pin | 50Ω coax. Active GPS patch antenna (3.3V bias via ferrite on SMA center pin). Passive patch also works.
GND | SMA shell | PGND | Board ground plane — SMA shell must connect to solid copper pour | Keep RF ground solid. No other traces under antenna footprint.

⚠ No antenna bias circuit visible for GNSS active antenna on J3. If using an active GPS patch antenna, you MUST add a bias-T: ferrite bead (100nF cap in series on signal line + 3.3V through ferrite on center pin). Passive antenna does not need this.

# Section 16 — Issues Found & Required Fixes

14 issues were identified during schematic review. Issues are ranked by severity.

# | Issue Found | Location | Severity | Recommended Fix

1 | EC200U VBAT connected to 5V rail directly — module max is 4.3V | U13 VBAT / U3 output | CRITICAL | Add AMS1117-4.2 or LP5907-4.2 LDO between 5V rail and EC200U VBAT. Powering at 5V WILL damage the module.
2 | No reverse polarity protection on OBD-II 12V input (Pin 16) | J6 Pin 16 | HIGH | Add series P-MOSFET (AO3401A) or Schottky diode (SS34) between OBD Pin 16 and VIN_12V net before LM2596.
3 | IO18 (SWP/SD3), IO19 (X4), IO23 (SHD/SD2) have no connections | ESP32 U1 | MEDIUM | Either assign to SPI (if SD card needed) or add 10kΩ pull-down resistors to prevent floating inputs causing spurious interrupts.
4 | No 4.7kΩ pull-up resistors explicitly shown on I2C SDA/SCL lines | I2C bus | HIGH | Add explicit 4.7kΩ from I2C_SDA to VCC_3V3 and 4.7kΩ from I2C_SCL to VCC_3V3. Required for I2C bus to function.
5 | DS3231M address conflict with MPU-6050 — both default to 0x68 | U8 DS3231M / U9 MPU-6050 | HIGH | Change MPU-6050 I2C address: connect AD0 pin to VCC_3V3 instead of GND → sets address to 0x69. DS3231M stays at 0x68.
6 | C3 (1µF supercap) on DS3231M VBAT is too small for RTC backup | U8 DS3231M pin VBAT | MEDIUM | Replace 1µF with a 3V CR2032 coin cell or at least a 100–220µF supercapacitor for meaningful RTC backup time.
7 | EC200U PWRKEY and RESET_N have no pull-up resistors | U13 PWRKEY / RESET_N | MEDIUM | Add 10kΩ pull-up from PWRKEY to 1.8V (VDD_EXT) to keep module powered. Same for RESET_N → keeps it deasserted.
8 | CAN bus termination resistors (120Ω) not visible in schematic | CAN bus | MEDIUM | Add two 120Ω resistors (0805) on CANH-CANL. Include solder-bridge jumpers so termination can be disabled if device is mid-bus.
9 | SIM card ESD protection not shown | SIM Card J1 | MEDIUM | Add PRTR5V0U2X (NXP) or similar dual TVS on USIM_DATA and USIM_CLK lines. Also add 22Ω series resistors on all SIM lines.
10 | F8 purpose not clear — appears between LM2596 ON/OFF and VCC_5V | U3 LM2596 area | LOW | Verify F8 is a polyfuse or ferrite bead. If it's a fuse, rate it 2A for the 5V rail. If ferrite, confirm it doesn't drop too much voltage.
11 | SENSOR_VP (IO36) and SENSOR_VN (IO39) are input-only, no external connections shown | ESP32 U1 | LOW | These are input-only ADC pins. Either use for battery voltage monitoring (via voltage divider from VIN_12V) or leave NC with explicit NC markers.
12 | No LED current limiting resistors explicitly shown for LED1 (D1) | LED1 / D1 area | MEDIUM | Add 330Ω (0402) in series with each LED for 3.3V supply (gives ~9mA). Verify 330Ω is in schematic between GPIO and LED anode.
13 | EC200U AUX_RXD/TXD and DBG_RXD/TXD left floating | U13 AUX/DBG UART | LOW | Tie AUX_RXD to 1.8V via 10kΩ (keep idle HIGH). AUX_TXD and DBG pins can be NC. Add test points for development.
14 | GRF_C1 and GRF_C2 pins on EC200U have no decoupling caps shown | U13 GRF pins | HIGH | Add 100nF capacitor from each GRF_C1 and GRF_C2 pin to GND. These are RF decoupling pins — required by Quectel hardware design guide.

✘ Fix Issues #1 (VBAT voltage), #5 (I2C address conflict), and #13 (MCP100 threshold) BEFORE ordering PCBs — these will cause the design to not function.

✔ Overall schematic structure is well-organized. All major functional blocks are present. The design covers CAN bus, GPS, 4G LTE, USB programming, RTC, IMU, I2C expansion, watchdog, and cloud connectivity.

OBD Tracker Schematic Report — Page

Schematic Connection Report — OBD Tracker (obd_tracker_with_gsm_and_gps.kicad.sch) | ALL Components — ALL Connections

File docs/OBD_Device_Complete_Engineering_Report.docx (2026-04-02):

INDUSTRIAL OBD TRACKING DEVICE

Complete Engineering Design Report

Quectel EC200U | ESP32 | CAN Bus | GPS/GNSS | 4G LTE Cloud

Hardware Design • KiCad Component List • Pin Connections • PCB Guidelines • Firmware Architecture

# 1. System Overview & Architecture

This document provides a complete, industrial-grade engineering reference for designing an OBD-II (On-Board Diagnostics) vehicle tracking device. The design reads real-time CAN bus data from a vehicle, acquires GPS/GNSS location via the Quectel EC200U module's built-in GNSS receiver, and transmits all telemetry to the cloud using 4G LTE. The ESP32 microcontroller serves as the central processing unit, chosen for its built-in CAN (TWAI) controller, triple UART interfaces, and low power sleep modes.

## 1.1 Design Goals

- Read CAN 2.0B frames from vehicle OBD-II port (ISO 15765-4 / SAE J1979)
- Acquire real-time GPS/GNSS coordinates using Quectel EC200U built-in GNSS
- Transmit data to cloud via 4G LTE (MQTT over TLS) using EC200U
- Operate continuously on vehicle 12V battery (9V–16V input range)
- Industrial temperature range: -40°C to +85°C
- Hardware watchdog for unattended long-term deployment
- OTA (Over-The-Air) firmware update capability
- ESD and transient protection on all external-facing signals

## 1.2 High-Level Architecture

Vehicle OBD-II Port → [CAN Transceiver SN65HVD230] → ESP32 TWAI → [EC200U UART] → 4G LTE → Cloud (MQTT/HTTPS) GPS Antenna → EC200U Built-in GNSS → NMEA → ESP32 UART → Parse → Cloud 12V Vehicle Power → LM2596 (5V Buck) → AMS1117 (3.3V LDO) → All logic USB Type-C → CP2102N (USB-UART) → ESP32 UART0 → Flash / Debug

# 2. Complete Hardware Component List with KiCad Names

The table below lists every component required for the complete OBD tracking PCB. KiCad names are provided in the format used in KiCad's standard symbol and footprint libraries (Device, Connector, Regulator_Linear, etc.). Custom or manufacturer-specific footprints are noted where required.

# | Component | KiCad Full Name | Specification | Qty | Purpose

1 | Microcontroller | ESP32-WROOM-32U | Dual-core 240 MHz, 4 MB Flash, WiFi+BT | 1 | Main MCU — CAN, UART, GPIO
2 | 4G LTE + GNSS Module | Quectel_EC200U-CN (Custom Footprint) | Cat-1 LTE, Built-in GNSS, UART I/F | 1 | 4G Internet + GPS
3 | CAN Bus Transceiver | SN65HVD230DR | 3.3V CAN ISO 11898, 1 Mbps, SO-8 | 1 | CAN physical layer interface
4 | Alt CAN Transceiver | MCP2551-I/SN | 5V CAN, fault-tolerant, SOP-8 | 1 | Alternative — 5V systems
5 | OBD-II Connector | CONN_OBD2_16PIN | Female 16-pin OBD-II (J1962 Type A) | 1 | Vehicle interface
6 | Buck Converter (12V→5V) | LM2596S-5.0 | 3A, 5V Fixed, TO-263-5, 150 kHz | 1 | Main 5V power rail
7 | LDO Regulator (5V→3.3V) | AMS1117-3.3 | 1A, SOT-223, Low dropout | 1 | 3.3V for ESP32 + EC200U
8 | LDO Regulator (5V→1.8V) | AMS1117-1.8 | 1A, SOT-223 | 1 | 1.8V for EC200U I/O if needed
9 | USB-UART Bridge | CP2102N-A02-GQFN28 | USB 2.0 Full Speed, QFN-28 | 1 | Firmware flashing + debug
10 | EEPROM | AT24C256C-SSHL-T | 256 Kbit, I2C, SOP-8 | 1 | Config + data logging
11 | RTC Module | DS3231SN# | ±2 ppm, I2C, SOIC-16, Battery backup | 1 | Accurate timekeeping
12 | Accelerometer/IMU | MPU-6050 | 6-axis MEMS, I2C, QFN-24 | 1 | Vibration + motion detect
13 | SIM Card Holder | SIM_CARD_8PIN_SMD | Nano SIM, push-push, SMD | 1 | SIM for EC200U
14 | LTE Main Antenna | CONN_SMA_EDGE | SMA Edge Mount, 50 Ohm | 1 | 4G LTE antenna connector
15 | GPS/GNSS Antenna | CONN_SMA_EDGE | SMA Edge Mount, active patch | 1 | GNSS antenna connector
16 | CAN Term Resistor | R_120R_0805 | 120 Ω, 0805, 1% | 2 | CAN bus termination
17 | Bulk Capacitor | C_1000uF_25V | 1000 µF, 25V, electrolytic | 2 | Input filtering
18 | Decoupling Cap 100nF | C_100nF_0402 | 100 nF, 50V, X7R, 0402 | 20 | Power decoupling
19 | Decoupling Cap 10µF | C_10uF_0805 | 10 µF, 10V, X5R, 0805 | 10 | Bulk decoupling
20 | Schottky Diode (reverse protect) | B5819WS | 40V, 1A, SOD-323 | 1 | Reverse polarity protection
21 | TVS Diode (12V rail) | SMAJ15A | 15V unidirectional, SMB | 2 | OBD line transient protection
22 | TVS Diode (CAN bus) | PESD1CAN | Dual-line CAN TVS, SOT-363 | 1 | CAN bus ESD protection
23 | Ferrite Bead | BLM21PG221SN1D | 220 Ω @ 100 MHz, 0805 | 4 | EMI filtering on power lines
24 | P-MOSFET (power switch) | AO3401A | P-MOS, 30V, 4A, SOT-23 | 1 | Soft power switching
25 | Reset IC | MCP809T-450I/TT | 3.3V supervisory, SOT-23 | 1 | System power-on reset
26 | LED Status (4x) | LED_0805 | Red/Green/Blue/Yellow, 0805 | 4 | Status indicators
27 | LED Resistors | R_330R_0402 | 330 Ω, 0402 | 4 | Current limiting for LEDs
28 | Pull-up Resistors | R_4k7_0402 | 4.7 kΩ, 0402 | 6 | I2C, UART pull-ups
29 | Filter Inductor | LM2596_INDUCTOR_100uH | 100 µH, 3A, SMD Power | 1 | LM2596 buck inductor
30 | Catch Diode | SS34 | 40V, 3A, Schottky, SMB | 1 | LM2596 freewheeling diode
31 | Debug Header | CONN_01X04_2.54MM | 4-pin 2.54mm UART debug | 1 | UART debug access
32 | JTAG/SWD Header | CONN_01X05_2.54MM | 5-pin 2.54mm | 1 | JTAG programming
33 | Watchdog IC | TPL5110DDCT | Nano-power Timer WDG, SOT-23-6 | 1 | Hardware watchdog reset
34 | I/O Expander (optional) | PCF8574T/3,518 | 8-bit I2C I/O, SOP-16 | 1 | Extra GPIO expansion
35 | Crystal Oscillator | Crystal_32MHz_SMD | 32 MHz, ±10 ppm, 3225 SMD | 1 | ESP32 external crystal

KiCad Library Paths: Device:*, Connector_PinHeader_2.54mm:*, Regulator_Linear:AMS1117-3.3, Regulator_Switching:LM2596S-5.0, Interface_CAN_LIN:SN65HVD230x, MCU_Module:ESP32-WROOM-32. EC200U requires a custom KiCad symbol and footprint — download from Quectel's official hardware design guide or SnapEDA.

# 3. ESP32 Suitability Analysis for OBD Tracking

## 3.1 Verdict: YES — ESP32 Works Excellently

The ESP32 is a very capable choice for this OBD tracking application. It has a built-in TWAI (Two-Wire Automotive Interface) controller which is fully compatible with CAN 2.0B / ISO 11898-1. Combined with three hardware UART interfaces (one for EC200U 4G, one for GNSS, one for USB debug), the ESP32 handles all communication requirements without any additional CAN controller IC. The following table details the complete capability assessment:

Parameter | ESP32 Value | Requirement | Status
CPU Speed | 240 MHz Dual-core | ≥ 80 MHz | ✓ PASS
RAM | 520 KB SRAM | ≥ 256 KB for buffers | ✓ PASS
Flash | 4 MB (WROOM) | ≥ 2 MB firmware | ✓ PASS
UART Count | 3 UARTs | 3 needed (CAN driver, EC200U, USB) | ✓ PASS
CAN Support | TWAI Controller (built-in) | CAN 2.0B required | ✓ PASS
I2C | 2 × I2C | 1 for sensors | ✓ PASS
Operating Voltage | 3.3V | 3.3V system | ✓ PASS
Operating Temp | -40°C to +85°C | -40°C to +85°C (automotive) | ✓ PASS
Deep Sleep Current | 10 µA | Low power for parking mode | ✓ PASS
WiFi | 802.11 b/g/n | Optional local config | ✓ BONUS
Bluetooth | BT 4.2 + BLE | OBD config via app | ✓ BONUS
Industrial Grade Alt | ESP32-S3 / STM32F4 | Higher reliability | ⚠ CONSIDER
Watchdog | Hardware TWDT | Required for automotive | ✓ PASS

## 3.2 Key ESP32 Advantages for This Design

- Built-in TWAI/CAN Controller: No external CAN controller IC needed — only the SN65HVD230 transceiver (physical layer) is required. Supports CAN 2.0B up to 1 Mbps.
- 3 Hardware UARTs: UART0 (USB Debug/Flash), UART1 (EC200U 4G LTE), UART2 (EC200U GNSS) — all three used simultaneously with no software overhead.
- Extremely Low Power Deep Sleep: 10 µA sleep current — perfect for parking mode (engine off) to prevent draining vehicle battery.
- Dual Core: Core 0 handles CAN data parsing and logging while Core 1 manages EC200U/cloud communication without blocking.
- Built-in WiFi: Enables local OTA updates via hotspot without needing 4G during development.
- Built-in BLE: Enables configuration via mobile app (change APN, MQTT server, etc.) without removing the device.

## 3.3 Limitations & Mitigations

- Not AEC-Q100 Qualified: ESP32 is consumer-grade, not automotive-certified. Mitigation: Use hardware watchdog (TPL5110), external supervisor IC, and conformal coating.
- Flash Wear on Heavy Logging: Frequent flash writes degrade longevity. Mitigation: Use external EEPROM (AT24C256) for config, buffer data in SRAM before writing.
- Industrial Alternative: For high-reliability applications, consider STM32F405 (ARM Cortex-M4, hardware CAN, -40 to +85°C, AEC-Q100 available) or ESP32-S3 for improved RF performance.

# 4. Complete Pin Connections & Signal Map

This section provides a complete wiring reference for the PCB designer and firmware engineer. Every signal between components is defined with GPIO assignment, direction, voltage level, and special notes.

Pin Group | ESP32 GPIO | Connected To | Signal Name | Notes
CAN Bus (SN65HVD230)
CAN TX | GPIO 5 | SN65HVD230 — Pin 1 (TXD) | CAN_TX | 3.3V logic
CAN RX | GPIO 4 | SN65HVD230 — Pin 4 (RXD) | CAN_RX | 3.3V logic
CAN H | — | Vehicle OBD pin 6 | CANH | 120Ω termination at each end
CAN L | — | Vehicle OBD pin 14 | CANL | Twisted pair to connector
EC200U — 4G LTE Module
UART2 TX | GPIO 17 | EC200U — MAIN_RXD (Pin 22) | MCU→EC200U | 115200 baud
UART2 RX | GPIO 16 | EC200U — MAIN_TXD (Pin 21) | EC200U→MCU | 115200 baud
PWRKEY | GPIO 26 | EC200U — PWRKEY (Pin 17) | MODULE_PWR | Active LOW, >500ms pulse
RESET | GPIO 27 | EC200U — RESET_N (Pin 19) | MODULE_RESET | Active LOW
STATUS | GPIO 35 | EC200U — STATUS (Pin 20) | MODULE_STATUS | Input — HIGH=on
RI | GPIO 34 | EC200U — RI (Pin 25) | RING_IND | Optional wake-up
DTR | GPIO 33 | EC200U — DTR (Pin 26) | DTR | Sleep control
GPS/GNSS (EC200U Built-in)
GNSS UART TX | GPIO 13 | EC200U — GNSS_TXD | GNSS_DATA | NMEA sentences @ 9600
GNSS UART RX | GPIO 12 | EC200U — GNSS_RXD | GNSS_CMD | Config commands
USB / Debug (CP2102N)
USB D+ | — | CP2102N — D+ | USB_DP | To USB type-C connector
USB D- | — | CP2102N — D- | USB_DM | To USB type-C connector
UART0 TX | GPIO 1 | CP2102N — RXD | DEBUG_TX | Programming + log
UART0 RX | GPIO 3 | CP2102N — TXD | DEBUG_RX | Programming + log
I2C Bus (SDA/SCL)
I2C SDA | GPIO 21 | EEPROM pin 5 + RTC pin 6 + MPU6050 pin 23 | I2C_SDA | 4.7kΩ pull-up to 3.3V
I2C SCL | GPIO 22 | EEPROM pin 6 + RTC pin 5 + MPU6050 pin 24 | I2C_SCL | 4.7kΩ pull-up to 3.3V
LEDs & Status
LED Power | GPIO 2 | Red LED → 330Ω → GND | LED_POWER | ON when system active
LED LTE | GPIO 14 | Blue LED → 330Ω → GND | LED_LTE | Blinks when connected
LED GPS | GPIO 15 | Green LED → 330Ω → GND | LED_GPS | ON when GPS fixed
LED ERR | GPIO 25 | Yellow LED → 330Ω → GND | LED_ERROR | Error/fault indicator
Watchdog (TPL5110)
WDG DONE | GPIO 32 | TPL5110 DONE pin | WDG_FEED | Pulse to reset watchdog
WDG RESET OUT | EN pin of ESP32 | TPL5110 RESET OUT | SYS_RESET | Resets ESP32 on timeout
Power Rails
OBD +12V (Pin 16) | — | LM2596 VIN | VIN_12V | 9–16V from vehicle
LM2596 OUT (5V) | — | AMS1117-3.3 VIN, EC200U VBAT | VCC_5V | Clean 5V rail
AMS1117 OUT (3.3V) | 3.3V VDD | ESP32, SN65HVD230, sensors | VCC_3V3 | Main logic rail
OBD GND (Pin 4/5) | GND | All component grounds | PGND/DGND | Star ground topology

# 5. OBD-II Connector Pin Assignment

The OBD-II 16-pin female connector (J1962 Type A) is the vehicle interface. Only relevant pins are connected — unused pins are left NC (no connect) with optional pull-down resistors for ESD safety.

OBD-II Pin | Signal | Connected To | Description
Pin 2 | SAE J1850 Bus+ | Not connected (NC) | Legacy protocol
Pin 4 | Chassis Ground | PGND — Power Ground | Vehicle chassis GND
Pin 5 | Signal Ground | DGND — Digital Ground | ECU signal GND
Pin 6 | CAN High (ISO 15765) | SN65HVD230 CANH | CAN-H — 2.5V–3.5V
Pin 7 | K-Line (ISO 9141) | NC or UART RX | Legacy K-Line (optional)
Pin 14 | CAN Low (ISO 15765) | SN65HVD230 CANL | CAN-L — 1.5V–2.5V
Pin 15 | L-Line (ISO 9141) | NC | Legacy L-Line
Pin 16 | Battery Positive (+12V) | LM2596 VIN + TVS Diodes | Main vehicle power 9–16V

IMPORTANT: Always place a 15V TVS diode (SMAJ15A) between Pin 16 (+12V) and GND, and a reverse-polarity Schottky diode (B5819WS) in series on the +12V line before the LM2596 input. The CAN lines (Pins 6 and 14) must have PESD1CAN TVS for ESD protection per ISO 7637-2.

# 6. Power Supply Design

## 6.1 Power Architecture Overview

The power supply is a two-stage design: a switching buck converter (LM2596) for high-efficiency 12V→5V conversion, followed by linear LDOs for clean 3.3V and 1.8V rails. The EC200U module's VBAT is powered directly from the 5V rail (the module has its own internal regulators). The design must handle the EC200U's peak transmit current of ~2A.

Stage | Input | Output | Component | Load Current | Efficiency
Vehicle Input | 9V–16V DC | Protected 12V | TVS + Schottky + Ferrite | 2A max | —
Buck 12V→5V | 9–16V | 5V ±2% | LM2596S-5.0 | 3A max | ~85%
LDO 5V→3.3V | 5V | 3.3V ±1% | AMS1117-3.3 | 1A max | 66%
LDO 5V→1.8V | 5V | 1.8V ±1% | AMS1117-1.8 | 500mA | 36%
EC200U VBAT | 5V direct | Internal regulated | Built-in LDO | 2A peak (4G TX) | —

## 6.2 Critical Power Design Rules

- Place 1000 µF electrolytic capacitor directly at OBD-II +12V input for bulk hold-up and spike suppression.
- EC200U VBAT: Place 100 µF + 10 µF + 100 nF capacitors within 5mm of EC200U VBAT pins. EC200U can draw 2A peak during 4G transmission.
- LM2596 Layout: Keep the LM2596, inductor (100µH), diode (SS34), and output capacitor in a tight loop. Minimize switching node (SW pin) trace area to reduce EMI.
- Separate PGND (power ground) and DGND (digital ground), connected at single star point near the LM2596 GND pin.
- Add a ferrite bead (BLM21PG221SN1D) between 5V and 3.3V power planes at the entry point to prevent switching noise coupling.

# 7. Schematic Block Description (KiCad Implementation)

## 7.1 Schematic Sheet Organization

For clean KiCad schematic organization, create separate hierarchical sheets for each functional block:

- Sheet 1 — Top Level: Shows all sub-sheets as hierarchical blocks with inter-sheet power flags and net labels
- Sheet 2 — Power Supply: LM2596, AMS1117-3.3, AMS1117-1.8, protection diodes, filter caps
- Sheet 3 — ESP32 Module: All ESP32-WROOM-32U pins with net labels, decoupling caps, reset circuit
- Sheet 4 — EC200U Module: All EC200U pins, antenna connectors, SIM holder, UART connections
- Sheet 5 — CAN Interface: SN65HVD230, OBD-II connector, TVS diodes, termination resistors
- Sheet 6 — Peripherals: USB (CP2102N), EEPROM, RTC, IMU, LEDs, watchdog, debug headers

## 7.2 Key Schematic Rules for KiCad

- Use PWR_FLAG symbols on all power nets (+12V, +5V, +3V3, GND) to prevent ERC errors.
- All net names must match between sheets: use identical net labels (CAN_TX, CAN_RX, UART1_TX, etc.) for cross-sheet connections.
- Add test point (TestPoint:TestPoint_Pad_2.0x2.0mm) on all critical signals: CAN_H, CAN_L, +5V, +3V3, UART1_TX, GPS_TX for in-circuit testing.
- EC200U: This requires a custom KiCad symbol. Create a symbol with all 70+ pins organized into functional groups (POWER, UART_MAIN, UART_GNSS, AUDIO, SIM, RF). Download reference schematic from Quectel's EC200U-XX Hardware Design document.
- CAN termination: Place two 120Ω resistors (R_120R_0805) with jumper (0Ω 0402 or solder bridge) in series so termination can be disabled if device is not at bus end.

## 7.3 EC200U Key Pin Connections (Quectel Reference)

EC200U Pin Reference — UART_MAIN: Pins 21(TXD), 22(RXD), 25(RI), 26(DTR). GNSS: Pins for GNSS_TXD/RXD. POWER: VBAT(Pins 1-4), PWRKEY(Pin 17), RESET_N(Pin 19), STATUS(Pin 20). SIM: USIM_VCC, USIM_DATA, USIM_CLK, USIM_RST. RF: MAIN_ANT (LTE), GNSS_ANT. Always refer to Quectel EC200U-XX Series Hardware Design V1.x for exact pin numbers as they may vary by variant (EC200U-CN, EC200U-EU, EC200U-AU).

# 8. PCB Design Guidelines

## 8.1 Layer Stack-up

Layer | Use | Copper Weight | Notes
Top (L1) | Component placement + signal traces | 35µm (1 oz) | Primary signal layer
GND (L2) | Solid copper ground plane | 35µm | Critical for EMI
PWR (L3) | Power distribution plane | 70µm (2 oz) | 5V + 3.3V planes
Bottom (L4) | Signal traces + thermal vias | 35µm | High-current traces
Via Type | Through-hole vias min 0.3mm drill | — | Blind/buried optional
PCB Size | 80mm × 60mm (recommended) | — | Fits standard enclosure
Impedance | 50Ω controlled for antenna traces | — | RF path critical
Surface Finish | HASL / ENIG recommended | — | ENIG for fine-pitch parts
Solder Mask | Green / Black | — | Both sides
Conformal Coat | Acrylic AR coating after assembly | — | Moisture protection

## 8.2 Critical PCB Layout Rules

### Antenna Placement

- LTE antenna connector (SMA): Place at board edge with minimum 15mm keep-out zone from all other components. Route the 50Ω microstrip trace from EC200U RF pin to SMA — trace width ~1.8mm on standard FR4 (calculate with impedance calculator for your actual stack-up).
- GPS antenna connector: Place at opposite edge from LTE antenna. 50Ω controlled impedance trace. Add ground stitching vias along antenna traces every 3mm.
- Do NOT route any signal traces under antenna connectors or RF traces. Place solid ground copper pour.

### CAN Bus Layout

- Route CANH and CANL as a differential pair, 120 mil spacing, equal length. Use 120Ω differential impedance if possible.
- Place PESD1CAN TVS diode as close as possible to the OBD-II connector — within 10mm.
- Place 120Ω termination resistors at the physical end of the CAN trace, near the OBD connector.

### Power Layout

- LM2596 switching loop: Keep the area enclosed by VIN, SW, diode, and output capacitor loop as small as possible to minimize EMI.
- EC200U VBAT decoupling: 100µF + 10µF + 100nF in parallel, placed within 5mm of VBAT pins.
- Pour a solid ground plane on Layer 2 (no cuts or gaps except for via anti-pads).
- Use thermal relief vias under LM2596 exposed pad and ESP32 GND pins.

### Component Placement Priority

- 1st: OBD-II connector (board edge, mechanically fixed)
- 2nd: Antenna connectors (SMA at board edges)
- 3rd: EC200U module (near antennas, away from switching supply)
- 4th: Power supply block (LM2596, LDOs — one corner)
- 5th: ESP32 (center of board for short traces to all peripherals)
- 6th: CAN transceiver (between ESP32 and OBD connector)
- 7th: USB connector (board edge, near CP2102N)
- 8th: All peripheral ICs, decoupling caps, LEDs

# 9. Cloud & Connectivity Architecture

Layer | Protocol | Platform Options | Data Rate
Device → Cloud | MQTT over TLS 1.2 | AWS IoT Core / HiveMQ / Mosquitto | ~1–5 KB/s typical
Alternate Protocol | HTTPS REST API | Any REST backend / Flask / FastAPI | On demand
Time Sync | NTP over EC200U | pool.ntp.org | At boot + hourly
OTA Firmware | HTTPS + ESP-IDF OTA | S3 bucket / GitHub Releases | On demand
Dashboard | WebSocket / MQTT Sub | Grafana / Node-RED / Custom | Real-time
Database | MQTT → InfluxDB / TimescaleDB | Time-series optimized | ~1M records/day

## 9.1 MQTT Data Payload Format

JSON Payload Example: { "device_id": "OBD_001", "timestamp": 1712000000, "gps": { "lat": 17.3850, "lon": 78.4867, "alt": 536.0, "speed_kmh": 45.2, "hdop": 1.2, "fix": 3 }, "can": { "rpm": 1800, "speed": 45, "coolant_temp": 85, "engine_load": 32, "throttle": 18, "vin": "1HGBH41JXMN109186" }, "power": { "vbat": 12.8, "ign": true }, "imu": { "ax": 0.12, "ay": -0.05, "az": 9.81 }, "signal": { "rssi": -87, "operator": "Airtel", "rat": "LTE" } }

# 10. Firmware Architecture (ESP-IDF / Arduino)

## 10.1 FreeRTOS Task Structure

- Task 1 — CAN_Reader (Core 0, Priority 10): Reads CAN frames using ESP32 TWAI driver. Sends parsed OBD-II PIDs to a FreeRTOS queue at 10 Hz.
- Task 2 — GPS_Parser (Core 0, Priority 8): Reads NMEA sentences from EC200U GNSS UART. Parses GPGGA/GPRMC for location, speed, fix quality.
- Task 3 — Cloud_Publisher (Core 1, Priority 6): Dequeues CAN + GPS data, constructs JSON payload, publishes to MQTT broker. Handles AT command interaction with EC200U.
- Task 4 — Watchdog_Feed (Core 1, Priority 15): Pulses TPL5110 DONE pin every 30 seconds. If any task hangs, this task stops and the hardware watchdog resets the system.
- Task 5 — OTA_Monitor (Core 1, Priority 3): Periodically checks for firmware update via HTTPS. Downloads and applies OTA using esp_https_ota.
- Task 6 — BLE_Config (Core 0, Priority 2): Exposes BLE GATT service for local device configuration (APN, MQTT server, sampling rate).

## 10.2 Power Management States

- ACTIVE Mode: Full operation — CAN sampling 10 Hz, GPS 1 Hz, MQTT publish every 5s. Total current ~450 mA @ 5V.
- IDLE Mode: Engine off detected (no CAN bus activity). GPS + LTE still active, publish rate drops to 60s. Current ~300 mA.
- SLEEP Mode: Parked >10 min. ESP32 light sleep, EC200U PSM (Power Saving Mode) active. GPS disabled. Current ~15 mA. Wake on CAN bus activity.
- DEEP SLEEP: Configurable after extended parking. ESP32 deep sleep 10 µA. EC200U eDRX mode. Wake via RTC timer or ignition detect on GPIO.

# 11. Industrial Design & Reliability Considerations

## 11.1 Enclosure Requirements

- IP54 or higher rated ABS/PC enclosure for under-dash or engine bay deployment.
- Recommended enclosure: Phoenix Contact or Hammond Manufacturing RP series (polycarbonate, IP65).
- OBD-II plug passes through enclosure via strain-relief grommet. Antenna connectors (SMA) mounted on enclosure panels.
- PCB must be secured with M3 standoffs (minimum 4 points) to prevent vibration damage.

## 11.2 EMC / EMI Compliance

- Target compliance: CISPR 25 Class 3 (automotive EMC), ISO 7637-2 (transient immunity).
- Apply conformal coating (Acrylic AR type, MG Chemicals 419C) after assembly and testing.
- Shield EC200U module with metal RF shield can if EMC testing fails on LTE harmonics.
- All external cables must have ferrite cores (Fair-Rite 0431167281) at PCB entry points.

## 11.3 Testing Checklist Before Production

- Power-on test: Verify 5V ± 100 mV and 3.3V ± 50 mV on test points
- CAN bus test: Use Vector CANalyzer or PEAK PCAN-USB to verify frame reception
- GPS cold start fix: Verify NMEA output within 90 seconds (open sky)
- 4G connectivity: Verify AT+CREG? returns registered, PING to server works
- MQTT publish: Verify data arrives at cloud dashboard within 10 seconds
- Temperature soak: -20°C to +70°C, verify operation at extremes
- Vibration test: 5-50 Hz, 0.5G for 2 hours per axis (IEC 60068-2-6)
- OTA update: Verify firmware update completes successfully over 4G

# 12. Quick Reference Summary

Item | Value
MCU | ESP32-WROOM-32U (or ESP32-S3 for industrial)
4G + GPS Module | Quectel EC200U-CN / EC200U-EU (variant per region)
CAN Transceiver | SN65HVD230DR (3.3V) or MCP2551 (5V systems)
Power Input | 9V – 16V DC from OBD-II Pin 16
Power Stages | LM2596S (12→5V) + AMS1117-3.3 (5→3.3V)
USB Bridge | CP2102N (USB 2.0 Full Speed)
Protocols | CAN 2.0B, MQTT/TLS, NMEA, AT Commands, I2C, UART
PCB | 4-Layer, 80×60mm, FR4, ENIG finish
KiCad Version | KiCad 8.x (Recommended for best library support)
Operating Temp | -40°C to +85°C (conformal coated)
Typical Current | ~450 mA @ 5V active | ~15 mA sleep mode
Cloud Protocol | MQTT over TLS 1.2 (AWS IoT / HiveMQ / custom broker)

NEXT STEPS: (1) Download Quectel EC200U Hardware Design Guide + KiCad footprint from Quectel website. (2) Download SN65HVD230 reference schematic from TI. (3) Begin KiCad schematic with hierarchical sheets as described in Section 7. (4) Order evaluation modules: ESP32-DevKitC, EC200U-CN EVB, OBD-II breakout board. (5) Prototype and test CAN → MQTT data pipeline before PCB design.

Industrial OBD Tracker | Confidential Engineering Document | Page 1

OBD TRACKING DEVICE — Complete Engineering Report | Quectel EC200U + ESP32 + CAN Bus + GPS/GSM

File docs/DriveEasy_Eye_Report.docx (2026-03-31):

DRIVEEASY EYE

AI Smart Dashcam

Product Development & Technical Reference Report

Prepared for:

DriveEasy Technologies

Hyderabad, Telangana, India

Version 4.2 | March 2026 | Confidential

# 1. Executive Summary

DriveEasy Eye is a Raspberry Pi 4 based AI-powered dashcam system designed to provide real-time vehicle safety alerts, live location tracking, and intelligent scene understanding at a fraction of the cost of commercially available dashcam products. The system is built entirely on open-source software and readily available hardware components, making it highly cost-effective to manufacture and easy to maintain.

The current prototype runs on a Raspberry Pi 4 with the Pi Camera module, streaming live video over WebRTC to a cloud signaling server. The AI pipeline uses YOLOv4-Tiny for real-time object detection, Google Gemini Vision (free tier) for contextual scene analysis, and OpenStreetMap Nominatim for reverse geocoding. All AI inference runs on the Pi itself with no recurring cloud compute costs.

Current prototype cost stands at approximately Rs. 8,000. With phased hardware additions outlined in this report, a fully featured consumer unit can be produced for Rs. 11,000 to Rs. 22,000 depending on specification level, while delivering AI features that no competitor product currently offers at any price point.

## 1.1 Key Metrics at a Glance

Metric | Value
Current hardware cost | Rs. 8,000
Target consumer price | Rs. 22,000 to Rs. 25,000
YOLO inference speed | 11 fps (Pi 4) — improvable to 20 fps with cooling fix
Video resolution | 1280 x 720 (upgradeable to 4K with Pi Camera v3)
AI warnings per frame | YOLO rule-based + Gemini Vision contextual (free tier)
Map API cost | Zero — OpenStreetMap Nominatim, unlimited free use
Gemini AI cost | Zero — 1,500 requests per day free tier

# 2. Software Feature Set

The DriveEasy Eye software stack has been developed iteratively across four versions. All features listed below are present in the current v4.2 codebase and are fully operational on Raspberry Pi 4.

## 2.1 Core Detection Features (YOLO-based)

Feature | Description | Status
Person detection | Detects pedestrians using YOLOv4-Tiny. Issues Pedestrian Ahead alert. | Active
Vehicle detection | Identifies cars, trucks, buses and motorbikes. Counts for traffic density. | Active
Traffic density | LOW below 3 vehicles, MEDIUM at 3 to 5, HIGH at 6 or more. | Active
Traffic signal detection | HSV colour detection on traffic light bounding box. Reads RED, YELLOW, GREEN. | Active
Lane detection | Canny edge + Hough lines. Active only when vehicles present. Angle-filtered to remove wall edges. | Active
Distance estimation | Pinhole camera model. Calculates real-world metres to each detected object. | Active
Collision warning | Bounding box height ratio. Vehicles only. SAFE, MEDIUM, HIGH levels. | Active
Tailgating alert | Triggers when nearest vehicle is under 5 metres. Separate caution at 10 metres. | Active
Rapid approach detector | Monitors bounding box growth rate. Alerts when vehicle grows over 20 percent per cycle. | Active

## 2.2 AI and Intelligence Features

Feature | Description | Status
Gemini Vision AI | Google Gemini 1.5 Flash analyzes full scene every 6 seconds. Detects road hazards, debris, weather. Free tier. | Active
Night mode enhancement | Auto-detects low light via mean brightness. Applies CLAHE on L channel. Shows NIGHT badge. | Active
Fatigue monitor | Tracks session duration. Warns at 2 hours. Repeats every 30 minutes. | Active
Voice alerts | espeak TTS reads warnings aloud. 5-second cooldown between alerts. | Active

## 2.3 Recording Features

Feature | Description | Status
Event snapshot | Auto-saves JPEG on collision detection. Stored in events/ folder. | Active
Event video buffer | Rolling 10-second AVI clip saved automatically on HIGH collision risk. | Active
Manual recording | HTTP toggle at port 8080. Access from phone on same WiFi. REC timer in header. | Active
Web dashboard REC button | One-tap record control from browser at PI_IP:5000. | Active

## 2.4 User Interface Features

UI Element | Content
Header left | Programmatic D logo + DriveEasy Eye AI Dashcam title in cyan
Header top-right | Line 1: latitude, longitude. Line 2: City, State, India. GPS status dot.
Header badges | NIGHT badge (orange) when low light. REC + timer (red) when recording.
Warning overlay | Red text warnings stacked from top-left. Updates every 5 frames.
Bounding box labels | Object class + estimated distance in metres shown above each box.
Footer line 1 | Left: timestamp. Right: FPS, CPU temperature, session uptime, GPS speed.
Footer line 2 | Centre: Persons, Vehicles, Traffic, Dist, Signal colour.

# 3. Hardware Configuration

## 3.1 Current Setup

The prototype uses a Raspberry Pi 4 with 4 GB RAM paired with a Pi Camera module. The Raspberry Pi 4 is the correct and recommended board for this application. It provides sufficient CPU performance for YOLO inference, enough RAM for the full software stack, and a MIPI CSI camera port for direct Pi Camera connection.

Current CPU temperature observed at 69 degrees Celsius indicates the unit is operating near its thermal limit without a heatsink. At 80 degrees Celsius the Pi 4 throttles clock speed, directly reducing YOLO inference FPS. Adding a heatsink and fan HAT is the highest priority hardware improvement and costs only Rs. 400.

## 3.2 Camera Module Comparison

Camera | Resolution | FPS | Price | Verdict
Pi Camera v1 | 5 MP / 1080p | 30 fps | Rs. 800 | Avoid — too old
Pi Camera v2 | 8 MP / 1080p | 30 fps | Rs. 2,800 | Good — likely current
Pi Camera v3 | 12 MP / 4K | 60 fps | Rs. 4,500 | Best upgrade choice
Pi HQ Camera + lens | 12 MP | 30 fps | Rs. 6,500 | Best clarity + wide angle
Pi Global Shutter | 1.6 MP | 60 fps | Rs. 5,000 | Not suitable — low res

## 3.3 GPS Module Wiring — NEO-6M or NEO-8M

The GPS module connects to the Raspberry Pi 4 UART pins. Use 3.3V power only. Connecting to the 5V pin will permanently damage the GPS module.

GPS Pin | Pi 4 Pin Number | Pi 4 Function | Wire Colour
VCC | Pin 1 | 3.3V Power | Red
GND | Pin 6 | Ground | Black
TX | Pin 10 | RXD (GPIO 15) | Green
RX | Pin 8 | TXD (GPIO 14) | Yellow

TX and RX are cross-connected. GPS TX connects to Pi RXD. GPS RX connects to Pi TXD. This is correct and required for UART communication.

# 4. Development Board Comparison

The Raspberry Pi 4 is the correct choice for this project. However, should cost reduction be required during product scaling, the following boards have been evaluated. Boards that cannot run Linux, Python, OpenCV, and YOLOv4-Tiny have been excluded from consideration.

## 4.1 Compatible SBC Comparison Table

Board | Price | CPU | RAM | YOLO FPS | Verdict
Raspberry Pi 4 | Rs. 6,500 | Cortex-A72 x4 | 4 GB | 11 fps | Current — keep
Orange Pi 5 | Rs. 5,500 | Cortex-A76 x8 | 4/8 GB | 20 fps | Best cheaper alt.
Orange Pi 3B | Rs. 3,200 | Cortex-A55 x4 | 4 GB | 10 fps | Good option
Rock Pi 4C | Rs. 5,000 | Cortex-A72 x6 | 4 GB | 14 fps | Good
Banana Pi M5 | Rs. 4,000 | Cortex-A55 x4 | 4 GB | 9 fps | Acceptable
Raspberry Pi 3B+ | Rs. 3,500 | Cortex-A53 x4 | 1 GB | 5 fps | Works, slow
Jetson Nano | Rs. 9,500 | A57 + 128-core GPU | 4 GB | 45 fps | Best AI perf.
Pi Zero 2W | Rs. 1,500 | Cortex-A53 x4 | 512 MB | 3 fps | Too slow
ESP32 | Rs. 300 | Xtensa 240 MHz | 520 KB | None | Cannot run code
Arduino | Rs. 400 | AVR 16 MHz | 2 KB | None | Cannot run code

## 4.2 Microcontroller Requirement

No separate microcontroller is required for the DriveEasy Eye dashcam. The Raspberry Pi 4 itself acts as the main controller. A separate microcontroller such as Arduino or STM32 would only be required in the following specific scenarios:

- Parking mode with motion-based wake from deep sleep (ATtiny85, cost Rs. 80)
- CAN bus integration for reading engine ECU data (STM32 + MCP2515, cost Rs. 600)
- Hardware debounced physical buttons for record or snapshot (Pi GPIO can handle this without an MCU)

For the current feature set, no additional microcontroller is needed or recommended.

# 5. Hardware Upgrade Roadmap

The following sections present a phased hardware upgrade plan. Each phase is independent and additive. Components are ordered by impact-to-cost ratio.

## 5.1 Phase 1 — Video Quality and Immediate Fixes (Rs. 6,600)

These upgrades have the highest immediate impact on video quality and system stability.

Component | Price | Function | Priority
Heatsink + Fan HAT | Rs. 400 | Prevents thermal throttling at 80C. Keeps CPU under 60C. Directly improves FPS. | Critical
Pi Camera v3 | Rs. 4,500 | Upgrades from 8 MP to 12 MP. Enables 4K recording. Better low-light sensitivity. | High
Wide angle lens 160 degrees | Rs. 600 | Covers full road width. Reduces blind zones at intersections. | High
Polarizing filter | Rs. 400 | Removes windshield reflections and glare. Significantly improves daytime image clarity. | Medium
NEO-8M GPS module | Rs. 700 | Faster satellite lock than NEO-6M. 2 to 3 metre accuracy. Powers live map and speed display. | High

## 5.2 Phase 2 — Safety and Connectivity (Rs. 2,950)

These components add new safety dimensions and ensure the dashcam operates reliably in a vehicle environment.

Component | Price | Function | Priority
MPU-6050 IMU | Rs. 200 | Detects harsh braking, sharp cornering, and pothole impacts. Triggers automatic event recording. | High
DC-DC converter 12V to 5V 5A | Rs. 400 | Powers Pi directly from car 12V battery. Eliminates USB adaptor failure risk. | High
4G LTE USB Dongle | Rs. 1,500 | Always-on internet for Gemini AI and live map, independent of phone WiFi hotspot. | Medium
64 GB microSD A2 | Rs. 500 | Class A2 rating required for sustained random write during video recording. | High
Piezo buzzer | Rs. 50 | Instant beep for collision alerts. Faster response than TTS voice synthesis. | Low
DHT22 sensor | Rs. 300 | Measures cabin temperature and humidity. Can trigger fog or condensation warnings. | Low

## 5.3 Phase 3 — Premium Product Specification (Rs. 4,250)

These components elevate the product to premium category and justify higher consumer pricing.

Component | Price | Function | Priority
UPS HAT (Waveshare) | Rs. 1,800 | Battery backup prevents data loss when car ignition is cut. Enables parking mode. | High for product
M.2 SSD + USB adapter | Rs. 1,800 | Faster sustained write than microSD. Eliminates card corruption under prolonged recording. | High for product
IR LED array | Rs. 400 | Illuminates scene in complete darkness for night vision without relying solely on CLAHE. | Medium
MQ-3 gas sensor | Rs. 250 | Detects alcohol and smoke inside cabin. Can trigger safety lockout or alert. | Medium

# 6. Bill of Materials — Consumer Product Version

The following is the recommended full BOM for a consumer-grade DriveEasy Eye unit targeting the Rs. 22,000 to Rs. 25,000 retail segment.

Component | Quantity | Unit Price | Total
Orange Pi 5 (4 GB) | 1 | Rs. 5,500 | Rs. 5,500
Pi Camera v3 | 1 | Rs. 4,500 | Rs. 4,500
Wide angle 160 degree CSI lens | 1 | Rs. 600 | Rs. 600
NEO-8M GPS module | 1 | Rs. 700 | Rs. 700
MPU-6050 IMU | 1 | Rs. 200 | Rs. 200
DC-DC power module 12V to 5V 5A | 1 | Rs. 400 | Rs. 400
64 GB microSD A2 | 1 | Rs. 800 | Rs. 800
Heatsink + fan | 1 | Rs. 300 | Rs. 300
Enclosure (acrylic or 3D printed) | 1 | Rs. 500 | Rs. 500
Piezo buzzer | 1 | Rs. 50 | Rs. 50
Total BOM Cost | | | Rs. 13,550

Recommended retail price: Rs. 22,000 to Rs. 25,000. Gross margin per unit: Rs. 8,450 to Rs. 11,450 before assembly, packaging, and warranty costs.

# 7. Competitor Analysis

The following table compares DriveEasy Eye against leading commercial dashcam products available in India. DriveEasy Eye is the only product in this category with on-device AI scene understanding, live map dashboard, and programmable safety logic.

Product | Price | Resolution | GPS | AI | Live Map
Nextbase 622GW | Rs. 25,000 | 4K | Yes | None | No
Viofo A229 Pro | Rs. 18,000 | 4K | Yes | None | No
Garmin Dash Cam 67W | Rs. 22,000 | 1440p | Yes | Basic | No
70Mai Pro Plus | Rs. 12,000 | 2.7K | Yes | Basic | No
DriveEasy Eye (Phase 2) | Rs. 11,000 | 1080p / 4K | Yes | Gemini AI + YOLO | Full web dashboard
DriveEasy Eye (Phase 3) | Rs. 22,000 | 4K | Yes | Gemini AI + YOLO | Full web dashboard

## 7.1 Competitive Advantage Summary

- Only dashcam with Gemini Vision AI contextual scene analysis — road debris, fog, unsafe behaviour detection
- Only dashcam with live OpenStreetMap web dashboard accessible from phone without any app install
- Only dashcam with programmable Python-based safety logic — fully customisable for fleet operators
- Reverse geocoding shows city and state in header — no competitor product shows this
- Manual and automatic video clip recording with HTTP API control from any browser
- Fatigue monitoring, rapid approach detection, and night mode CLAHE — all unique to this product

# 8. Immediate Action Items

The following actions are recommended in priority order to improve the current prototype before any hardware additions.

No. | Action | Reason | Cost
1 | Add heatsink and fan HAT | CPU is at 69C. Throttling starts at 80C and reduces YOLO fps from 11 to 6. | Rs. 400
2 | Set CPU to performance governor | Unlocks full 1.8 GHz on all cores. Immediate fps improvement at zero cost. | Free
3 | Upgrade to Pi Camera v3 | Current 8 MP sensor is the biggest video quality bottleneck. | Rs. 4,500
4 | Use 64 GB Class A2 microSD | Standard cards have slow random write and will corrupt under sustained video recording. | Rs. 800
5 | Connect NEO-8M GPS | Enables real location in header instead of default Hyderabad placeholder. | Rs. 700

## 8.1 Free Software Command — CPU Governor

Run this command once on the Pi to unlock full CPU speed at no cost. This alone can improve YOLO inference FPS by 15 to 20 percent:

echo performance | sudo tee /sys/devices/system/cpu/cpu*/cpufreq/scaling_governor

To check current throttling status:

vcgencmd get_throttled

A result of 0x0 means no throttling. Any other value means the CPU is being reduced in speed due to heat or power issues.

# 9. Free APIs and Services Used

All external services used in DriveEasy Eye are free of charge for the usage levels of a dashcam application. No paid API subscriptions are required to run the full feature set.

Service | Used For | Free Limit | Daily Usage
Google Gemini 1.5 Flash | Scene analysis, hazard detection | 1,500 requests per day | ~600 per 2-hour drive
OSM Nominatim | Reverse geocoding city and state | Unlimited, reasonable use | 1 per 30 seconds
CartoDB Dark Map Tiles | Live map background tiles | Unlimited | On demand per zoom level
Google STUN Server | WebRTC ICE negotiation | Unlimited | Once per session
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

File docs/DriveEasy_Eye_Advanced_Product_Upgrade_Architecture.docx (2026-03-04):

# DriveEasy Eye - Advanced Product Upgrade Architecture

Prepared for Product Development Expansion

## 1. Advanced Recording System (Industrial Grade)

### 1.1 Continuous Loop Recording

- Configurable recording segments (1 / 3 / 5 minutes)
- Automatic overwrite of oldest files
- Structured folders: /normal, /event, /parking

### 1.2 Event Locked Recording

- Triggered by accident detection (IMU G-force)
- Harsh braking via OBD data
- AI collision detection
- Manual emergency button
- Locked files protected from overwrite

### 1.3 AI Smart Clip Recording

- Circular buffer system
- Save 10 seconds before + 10 seconds after event
- Reduced storage usage
- Reduced LTE data upload cost
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

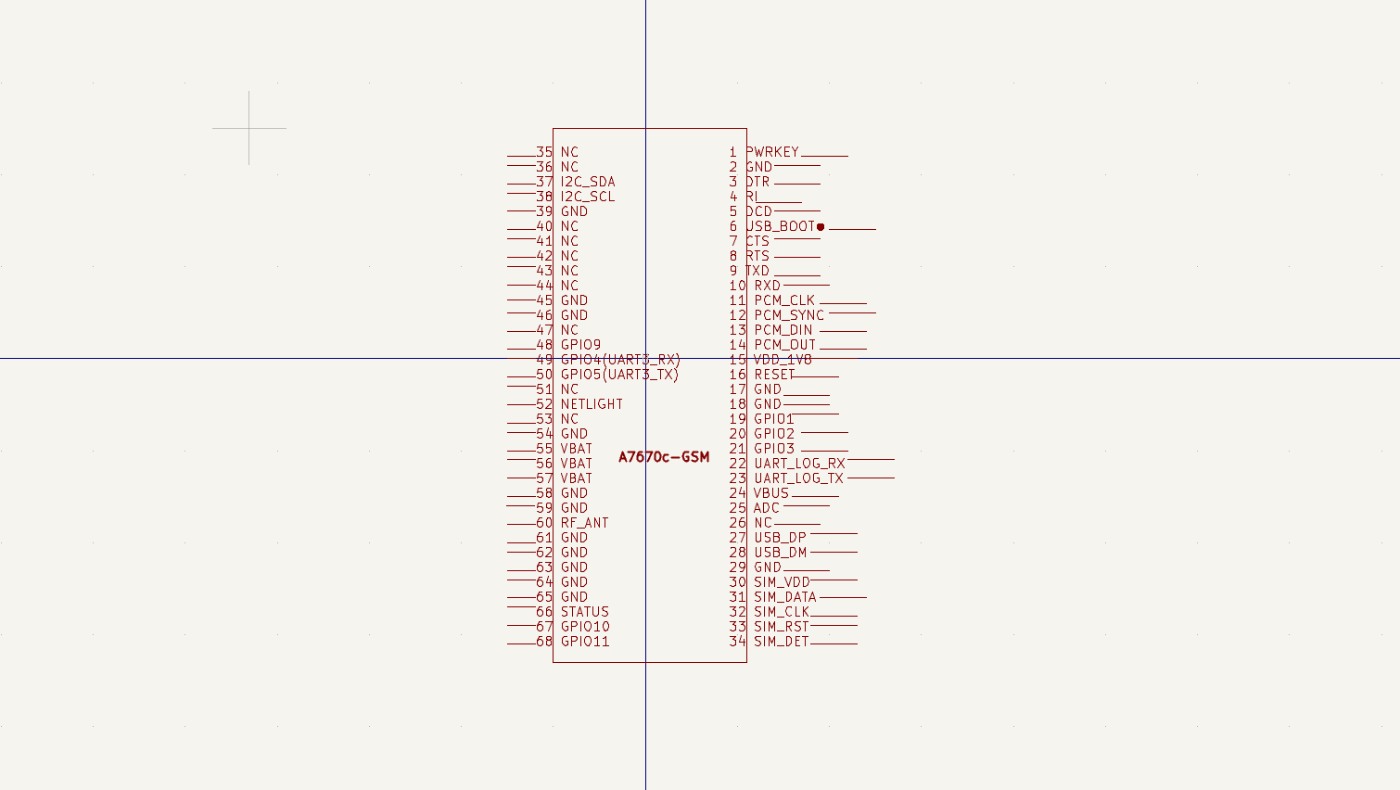
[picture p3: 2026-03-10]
docs/hardware/dashcam/a7670c_gsm.png

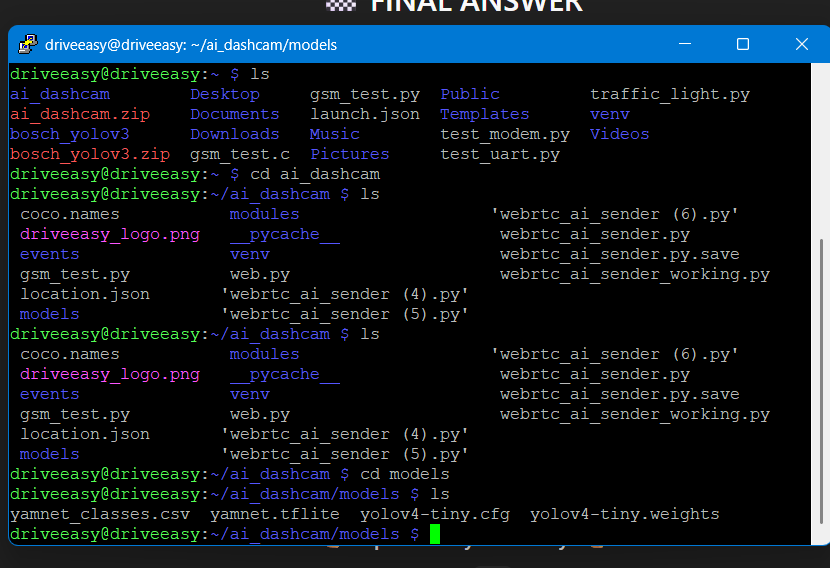
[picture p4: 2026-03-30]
docs/Screenshot 2026-03-30 182053.png

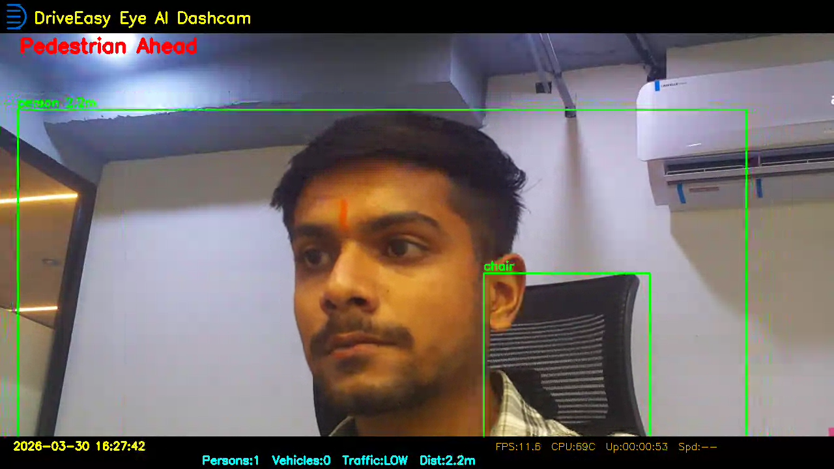
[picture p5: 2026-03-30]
software/videoframe_13675.png

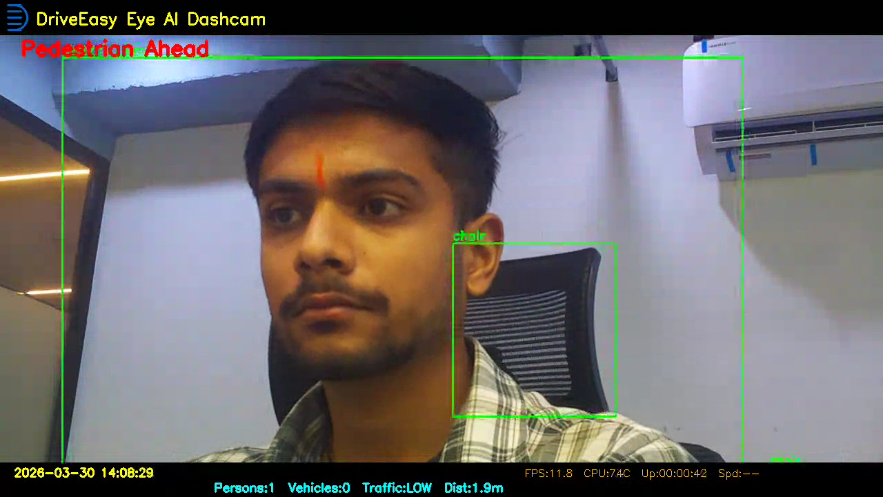
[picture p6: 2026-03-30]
software/videoframe_41555.png

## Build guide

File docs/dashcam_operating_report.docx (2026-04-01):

# DriveEasy AI Dashcam Deployment Report

System: Raspberry Pi-Based AI Dashcam
Version: Deployment v1.0

## 1. Objective

This document provides a complete, professional deployment guide for setting up the DriveEasy AI Dashcam system on a new Raspberry Pi. The goal is to ensure:

- Smooth, lag-free video streaming
- Reliable camera operation
- Automatic startup on boot
- Scalable architecture for future AI integration

## 2. System Requirements

### Hardware

- Raspberry Pi (Pi 3 / Pi 4 / Pi 5 recommended)
- Raspberry Pi Camera Module (CSI) or USB webcam
- MicroSD Card (16GB+ recommended)
- Stable power supply
- Internet connectivity (WiFi or Ethernet)

### Software

- Raspberry Pi OS (latest version)
- Python 3.9+
- Required Python libraries (aiortc, OpenCV, etc.)

## 3. Operating System Installation

1. Install Raspberry Pi OS using Raspberry Pi Imager.
2. Enable the following during setup:
  - SSH access
  - WiFi configuration
3. Boot the Raspberry Pi and log in.

## 4. System Initialization

Update the system packages:

sudo apt update

sudo apt upgrade -y

## 5. Camera Configuration

Enable camera interface:

sudo raspi-config

Navigate to:

Interface Options → Camera → Enable

Reboot the system:

sudo reboot

Verify camera functionality:

libcamera-hello

## 6. Dependency Installation

Install required system packages:

sudo apt install -y python3-pip python3-venv python3-opencv libcamera-apps

## 7. Project Setup

Create project directory:

mkdir ~/ai_dashcam

cd ~/ai_dashcam

## 8. Python Virtual Environment

Create and activate virtual environment:

python3 -m venv venv

source venv/bin/activate

Install required Python libraries:

pip install aiortc websockets av numpy opencv-python

## 9. Application Deployment

Create the main application file:

nano webrtc_ai_sender.py

Paste the working streaming code into this file.

## 10. Manual Testing

Run the application:

python webrtc_ai_sender.py

Verify:

- Camera initializes successfully
- No runtime errors
- Video stream appears on UI

## 11. Camera Resource Handling

Prevent camera lock issues:

sudo pkill -f libcamera

This ensures no process blocks camera access.

## 12. Auto-Start Service Configuration

Create systemd service:

sudo nano /etc/systemd/system/driveeasy.service

Add configuration:

[Unit]

Description=DriveEasy AI Dashcam

After=network-online.target

Wants=network-online.target

[Service]

User=pi

WorkingDirectory=/home/pi/ai_dashcam

ExecStartPre=/bin/sleep 5

ExecStartPre=-/usr/bin/pkill -f libcamera

ExecStart=/home/pi/ai_dashcam/venv/bin/python /home/pi/ai_dashcam/webrtc_ai_sender.py

Restart=always

RestartSec=5

StandardOutput=journal

StandardError=journal

[Install]

WantedBy=multi-user.target

## 13. Enable and Start Service

sudo systemctl daemon-reload

sudo systemctl enable driveeasy.service

sudo systemctl start driveeasy.service

## 14. Verification

Check service status:

systemctl status driveeasy.service

Expected output:

active (running)

## 15. Boot Validation

Reboot system:

sudo reboot

After reboot:

systemctl status driveeasy.service

Confirm automatic startup.

## 16. Supported Camera Modules

- Raspberry Pi Camera Module v2 (IMX219)
- Raspberry Pi Camera Module v3 (IMX708)
- USB webcams (UVC compatible)

## 17. Common Issues & Solutions

Issue | Cause | Solution
Camera busy | Multiple processes | sudo pkill -f libcamera
Module not found | venv not active | Activate venv
Service fails | Path/config error | Check journal logs
No video stream | WebRTC issue | Verify signaling

## 18. Performance Optimization Notes

- Use lower resolution (640×480) for smoother performance
- Avoid heavy AI models during baseline testing
- Use frame skipping for AI workloads
- Separate AI processing and streaming (future enhancement)

## 19. Future Enhancements

- AI-based object detection (YOLO / TensorFlow Lite)
- GPS integration and mapping
- Event-based recording system
- Gemini AI assistant integration
- Multi-threaded processing pipeline

## 20. Conclusion

The DriveEasy AI Dashcam system has been successfully structured for:

- Reliable deployment
- Smooth video streaming
- Scalable architecture
- Production-ready service execution

This setup ensures a plug-and-play experience for any new Raspberry Pi device with minimal configuration effort.

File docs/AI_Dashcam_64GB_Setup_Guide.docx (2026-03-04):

# AI Dashcam Setup Guide (64 GB SD Card)

This document provides a complete step-by-step guide to set up the AI Dashcam system on a Raspberry Pi using a 64 GB SD card.

It supports YOLOv8 object detection, WebRTC live streaming, and video recording.

==================================================

SYSTEM REQUIREMENTS

==================================================

• Raspberry Pi 4 or Pi 5

• 64 GB SD Card (expanded filesystem)

• Raspberry Pi Camera / USB Camera

• Internet connection (Wi-Fi / Hotspot / GSM)

• Raspberry Pi OS (Bookworm / Trixie)

==================================================

PROJECT FOLDER STRUCTURE

==================================================

/home/driveeasy/ai_dashcam/

├── main.py

├── detector.py

├── overlay.py

├── traffic_light.py

├── recorder.py

├── video_source.py

├── webrtc_ai_sender.py

├── requirements.txt

├── models/

│ └── yolov8n.pt

└── recordings/

==================================================

STEP 1: CLEAN SYSTEM

==================================================

cd ~

rm -rf ~/.cache/pip

sudo apt clean

sudo apt autoremove -y

sudo journalctl --vacuum-size=200M

==================================================

STEP 2: VERIFY STORAGE

==================================================

df -h

If filesystem is not expanded:

sudo raspi-config

→ Advanced Options → Expand Filesystem → Reboot

==================================================

STEP 3: CHECK INTERNET

==================================================

ping -c 3 8.8.8.8

ping -c 3 github.com

==================================================

STEP 4: INSTALL SYSTEM PACKAGES

==================================================

sudo apt update

sudo apt install -y python3-full python3-venv python3-opencv python3-pip git ffmpeg

==================================================

STEP 5: CREATE VIRTUAL ENVIRONMENT

==================================================

cd ~/ai_dashcam

python3 -m venv venv

source venv/bin/activate

==================================================

STEP 6: INSTALL PYTHON LIBRARIES

==================================================

pip install --upgrade pip wheel setuptools

pip install numpy python-dateutil

pip install ultralytics

==================================================

STEP 7: DOWNLOAD YOLOv8 MODEL

==================================================

mkdir -p models

cd models

wget https://github.com/ultralytics/assets/releases/download/v8.0.0/yolov8n.pt

cd ..

==================================================

STEP 8: TEST YOLO MODEL

==================================================

from ultralytics import YOLO

YOLO("models/yolov8n.pt")

==================================================

STEP 9: CHECK CAMERA

==================================================

ls /dev/video*

==================================================

STEP 10: RUN AI DASHCAM

==================================================

cd ~/ai_dashcam

source venv/bin/activate

python main.py

==================================================

OUTPUT

==================================================

• Live WebRTC streaming

• Vehicle and traffic signal detection

• Signal timer overlay

• Date & time overlay

• Recorded MP4 videos

==================================================

IMPORTANT NOTES

==================================================

• Always activate virtual environment before running

• 64 GB SD card is recommended

• Do not install YOLOv4-tiny for this setup

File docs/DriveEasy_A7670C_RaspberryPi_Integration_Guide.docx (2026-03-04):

# DriveEasy GSM Integration Guide

A7670C LTE Module Integration with Raspberry Pi 4

## 1. Introduction

This document explains the complete hardware and software integration process for connecting the A7670C LTE GSM module with Raspberry Pi 4. It also clarifies limitations related to UART-only modules and streaming applications.

## 2. Important Architecture Clarification

The A7670C module without a USB interface exposes only UART (TX/RX) communication. UART supports AT commands and basic TCP socket communication but is NOT suitable for high-bandwidth applications such as WebRTC video streaming.

UART Maximum Practical Throughput:

- 115200 baud ≈ 11 KB/s

- 921600 baud ≈ 90 KB/s

WebRTC streaming requires 300–800 KB/s minimum.

Conclusion: UART-only A7670C cannot support real-time video streaming.

## 3. Hardware Connection (UART Mode)

If using UART interface, connect as follows:

A7670C TXD → Raspberry Pi RX (GPIO15, Pin 10)

A7670C RXD → Raspberry Pi TX (GPIO14, Pin 8)

A7670C GND → Raspberry Pi GND (Pin 6)

A7670C VCC → External 4.0V regulated supply

IMPORTANT: The A7670C requires 3.8V–4.2V with peak current up to 2A. Do NOT power the module directly from Raspberry Pi 5V pin. Use a buck converter (5V → 4V) with at least 1000µF capacitor near VBAT.

## 4. Enable UART on Raspberry Pi

Run:

sudo raspi-config

Navigate to: Interface Options → Serial Port

Disable login shell over serial

Enable serial hardware

Reboot the system

## 5. Test AT Communication

Install minicom:

sudo apt install minicom

Run:

sudo minicom -b 115200 -o -D /dev/serial0

Type AT and expect response OK.

## 6. LTE Data Connection Using AT Commands

Basic command sequence for Airtel IoT SIM:

AT+CPIN?

AT+CSQ

AT+CREG?

AT+CGATT=1

AT+CGDCONT=1,"IP","airtelgprs.com"

AT+NETOPEN

AT+IPADDR

Note: This creates a TCP/IP session inside the module, but does not create a Linux network interface (like wwan0).

## 7. Recommended Production Architecture

For real-time AI dashcam streaming using WebRTC, the recommended solution is:

- A7670C USB variant OR

- SIM7600 USB LTE modem OR

- Standard 4G USB LTE dongle

These devices create a Linux network interface (wwan0), allowing Raspberry Pi to use LTE as a normal internet connection.

## 8. Final Recommendation for DriveEasy System

For a production-grade AI dashcam system requiring cloud streaming, WiFi + USB LTE modem architecture is strongly recommended over UART-only GSM modules.

This ensures:

- Stable Internet Interface

- Full WebRTC compatibility

- Higher upload bandwidth

- Reduced system complexity

End of Document

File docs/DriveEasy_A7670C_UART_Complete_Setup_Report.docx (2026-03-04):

# DriveEasy A7670C GSM UART Integration Report

This document provides a complete step-by-step professional guide to connect and configure the A7670C GSM LTE module with Raspberry Pi 4 using UART protocol.

## 1. Hardware Requirements

- Raspberry Pi 4

- A7670C GSM LTE module (UART version)

- Airtel IoT SIM card (activated with data plan)

- External 4.0V regulated power supply (minimum 2A current capability)

- 1000µF capacitor across VBAT and GND (recommended)

- Connecting wires

## 2. Power Supply Requirements (Critical)

The A7670C requires a stable 3.8V–4.2V supply with peak current up to 2A. Do NOT power the module directly from Raspberry Pi 5V pin. Use a 5V to 4V buck converter and ensure GSM GND is connected to Raspberry Pi GND.

## 3. UART Wiring Connections

Connect the module as follows:

A7670C TXD → Raspberry Pi GPIO15 (Pin 10)

A7670C RXD → Raspberry Pi GPIO14 (Pin 8)

A7670C GND → Raspberry Pi GND (Pin 6)

A7670C VCC → External 4.0V supply

Ensure TX is connected to RX and RX to TX. Common ground is mandatory.

## 4. Enable UART on Raspberry Pi

Run the following command:

sudo raspi-config

Navigate to: Interface Options → Serial Port

Set 'Login shell over serial' to NO

Set 'Serial hardware enabled' to YES

Reboot the Raspberry Pi using:

sudo reboot

## 5. Disable Bluetooth UART Conflict (Recommended)

Edit boot configuration file:

sudo nano /boot/config.txt

Add the following lines at the bottom:

dtoverlay=disable-bt

enable_uart=1

Save and reboot: sudo reboot

## 6. Verify Serial Port

After reboot, check UART device:

ls -l /dev/serial0

It should point to ttyAMA0.

## 7. Install Serial Terminal Software

Install screen utility:

sudo apt update

sudo apt install screen

## 8. Open Serial Communication

Use the following command:

sudo screen /dev/ttyAMA0 115200

If no response, try 9600 baud rate:

sudo screen /dev/ttyAMA0 9600

## 9. Test AT Communication

Type the following command inside screen:

AT

Expected response: OK

## 10. SIM and Network Check Commands

Check SIM status: AT+CPIN?

Check signal strength: AT+CSQ

Check network registration: AT+CREG?

Attach to packet service: AT+CGATT=1

Set APN (Airtel example): AT+CGDCONT=1,"IP","airtelgprs.com"

Activate PDP: AT+CGACT=1,1

Open network: AT+NETOPEN

Get IP address: AT+IPADDR

## 11. Test HTTP Connectivity

Initialize HTTP: AT+HTTPINIT

Set CID: AT+HTTPPARA="CID",1

Set URL: AT+HTTPPARA="URL","http://httpbin.org/get"

Start GET request: AT+HTTPACTION=0

Read response: AT+HTTPREAD

## 12. Troubleshooting Guide

- If garbage characters appear, check baud rate.

- Ensure common ground between Pi and GSM.

- Verify TX/RX are not swapped.

- Ensure stable 4V power supply.

- Disable serial console and Bluetooth UART.

End of Report

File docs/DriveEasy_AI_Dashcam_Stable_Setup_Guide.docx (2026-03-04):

# DriveEasy Eye - Stable Raspberry Pi AI Dashcam Setup Guide

This document provides a complete step-by-step stable setup for Raspberry Pi 4 AI Dashcam with WebRTC streaming and Picamera2 support.

Recommended Environment:

- Raspberry Pi OS Bookworm (64-bit)

- Python 3.11 (Stable Version)

- Picamera2 via apt (NOT pip)

- YOLOv4-tiny with OpenCV DNN

## STEP 1: Verify Operating System

Run the following command:

cat /etc/os-release

Ensure it shows VERSION="12 (bookworm)"

## STEP 2: Check Python Version

Run:

python3 --version

Ensure version is Python 3.11.x

If Python 3.13 is installed, downgrade to Python 3.11 for stability.

## STEP 3: Update System

Run:

sudo apt update

sudo apt full-upgrade -y

## STEP 4: Install Stable Camera Stack

Install official camera packages:

sudo apt install -y python3-picamera2 libcamera-apps python3-opencv python3-av python3-numpy

Do NOT install picamera2 using pip.

## STEP 5: Test Camera

Test libcamera preview:

libcamera-hello

Test Picamera2 in Python:

python3

from picamera2 import Picamera2

picam2 = Picamera2()

picam2.start()

print('Camera working stable')

## STEP 6: Create Virtual Environment for WebRTC

Navigate to project folder:

cd ~/ai_dashcam

Create virtual environment:

python3 -m venv venv

Activate it:

source venv/bin/activate

## STEP 7: Install WebRTC Dependencies

Inside virtual environment install:

pip install aiortc==1.5.0

pip install websockets==11.0.3

## STEP 8: Run AI Dashcam Sender

Activate venv and run:

cd ~/ai_dashcam

source venv/bin/activate

python webrtc_ai_sender.py

## Stable Working Stack Summary

- OS: Raspberry Pi OS Bookworm 64-bit

- Python: 3.11

- Picamera2: apt version

- OpenCV: apt version

- aiortc: 1.5.0

- websockets: 11.0.3

- YOLO: yolov4-tiny (OpenCV DNN)

This configuration ensures stable camera initialization, WebRTC streaming, and AI detection without allocator or compatibility errors.

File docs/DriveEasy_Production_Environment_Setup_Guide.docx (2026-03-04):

# DriveEasy Production Environment Setup Guide

This document lists all required libraries, models, and system packages needed to run the DriveEasy AI Dashcam system properly on Raspberry Pi 4 using YOLOv4-tiny and OpenCV DNN.

## 1. System-Level Packages (Install using apt)

Run the following commands on Raspberry Pi:

sudo apt update

sudo apt install python3-opencv python3-numpy -y

sudo apt install tesseract-ocr -y

sudo apt install python3-picamera2 -y

## 2. Virtual Environment Setup

Create virtual environment with system packages access:

python3 -m venv venv --system-site-packages

source venv/bin/activate

## 3. Python Libraries to Install in venv

Install only required packages inside venv:

pip install aiortc websockets av norfair

Optional (if using OCR): pip install pytesseract

## 4. Required Models

Place the following files inside your project folder:

- yolov4-tiny.cfg

- yolov4-tiny.weights

- coco.names

## 5. Optional Enhancements

- Custom YOLOv4-tiny weights (trained with Bosch + BDD100K)

- Timer digit dataset (if using traffic timer detection)

- Norfair tracking for smoother object tracking

## 6. Final Production Stack Summary

Camera → YOLOv4-tiny (OpenCV DNN) → Traffic Signal Color Detection → Distance Estimation → Norfair Tracking → Collision Alert → WebRTC Streaming

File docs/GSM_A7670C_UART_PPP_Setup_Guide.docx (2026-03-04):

# GSM (A7670C) Internet Setup Guide Raspberry Pi + UART + PPP Method

This document provides a complete step-by-step procedure to:
1) Verify GSM Internet connectivity using AT commands.
2) Configure PPP over UART to provide internet access inside Raspberry Pi Linux.
sudo reboot

## SECTION 1: Hardware Requirements

• Raspberry Pi 4

• A7670C GSM/LTE Module

• FTDI (CP210x) USB to UART Converter

• Airtel IoT SIM

• Stable 4.0V–4.2V Power Supply (Minimum 2A current)

• LTE Antenna connected to GSM module

## SECTION 2: Wiring Connections (UART)

FTDI TX → GSM RX

FTDI RX → GSM TX

FTDI GND → GSM GND

⚠ Ensure FTDI logic level is set to 3.3V.

⚠ Ensure power supply can provide at least 2A peak current.

## SECTION 3: Verify GSM Connectivity (AT Commands)

1. Connect GSM via FTDI to Raspberry Pi.

2. Check serial port:

ls /dev/ttyUSB*

3. Open serial terminal:

sudo screen /dev/ttyUSB0 115200

4. Test modem response:

AT

5. Check SIM status:

AT+CPIN?

6. Check signal strength:

AT+CSQ

7. Check network registration:

AT+CREG?

8. Attach to network:

AT+CGATT=1

9. Set APN (Airtel IoT):

AT+CGDCONT=1,"IP","airtel.iot"

10. Open data network:

AT+NETOPEN

11. Check assigned IP:

AT+IPADDR

If an IP like 10.x.x.x appears, GSM internet is active inside the modem.

Exit screen using: CTRL + A, then K, then Y.

## SECTION 4: Disable WiFi Before PPP

sudo ifconfig wlan0 down

## SECTION 5: Configure PPP Over UART

1. Create PPP peer file:

sudo nano /etc/ppp/peers/a7670

Paste the following:

/dev/ttyUSB0 115200
connect "/usr/sbin/chat -v -f /etc/ppp/chat-a7670"
noauth
defaultroute
usepeerdns
lock
debug

2. Create chat script file:

sudo nano /etc/ppp/chat-a7670

Paste the following:

ABORT "ERROR"
ABORT "NO CARRIER"
"" AT
OK ATE0
OK AT+CGDCONT=1,"IP","airtel.iot"
OK ATD*99***1#
CONNECT ""

## SECTION 6: Start PPP Connection

Stop any existing PPP session:

sudo poff

Start PPP:

sudo pon a7670

Wait 15–20 seconds, then verify:

ifconfig

If successful, interface 'ppp0' will appear.

Test internet:

ping 8.8.8.8

## SECTION 7: Debugging PPP

If PPP fails, check logs:

sudo plog

Ensure modem is not rebooting and power supply is stable.

## Important Notes

• UART speed limits bandwidth (~8–10 KB/sec).

• Suitable for telemetry, MQTT, small HTTP requests.

• Not recommended for video streaming (WebRTC).

• For high bandwidth applications, use USB LTE interface instead of UART.

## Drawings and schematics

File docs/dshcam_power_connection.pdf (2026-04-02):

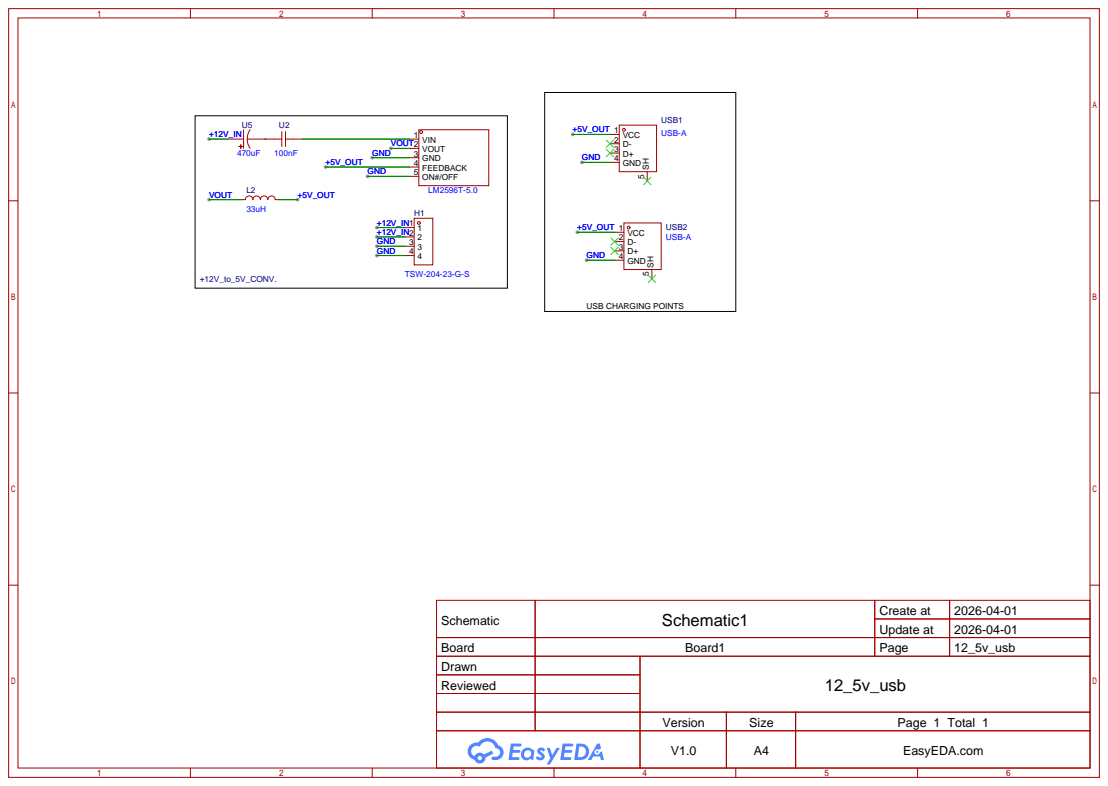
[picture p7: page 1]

Schematic | Schematic1 | Create at | 2026-04-01

Update at | 2026-04-01

Board | Board1 | Page | 12_5v_usb
Drawn | | 12_5v_usb
Reviewed

Version | Size | Page 1 Total 1
V1.0 | A4 | EasyEDA.com

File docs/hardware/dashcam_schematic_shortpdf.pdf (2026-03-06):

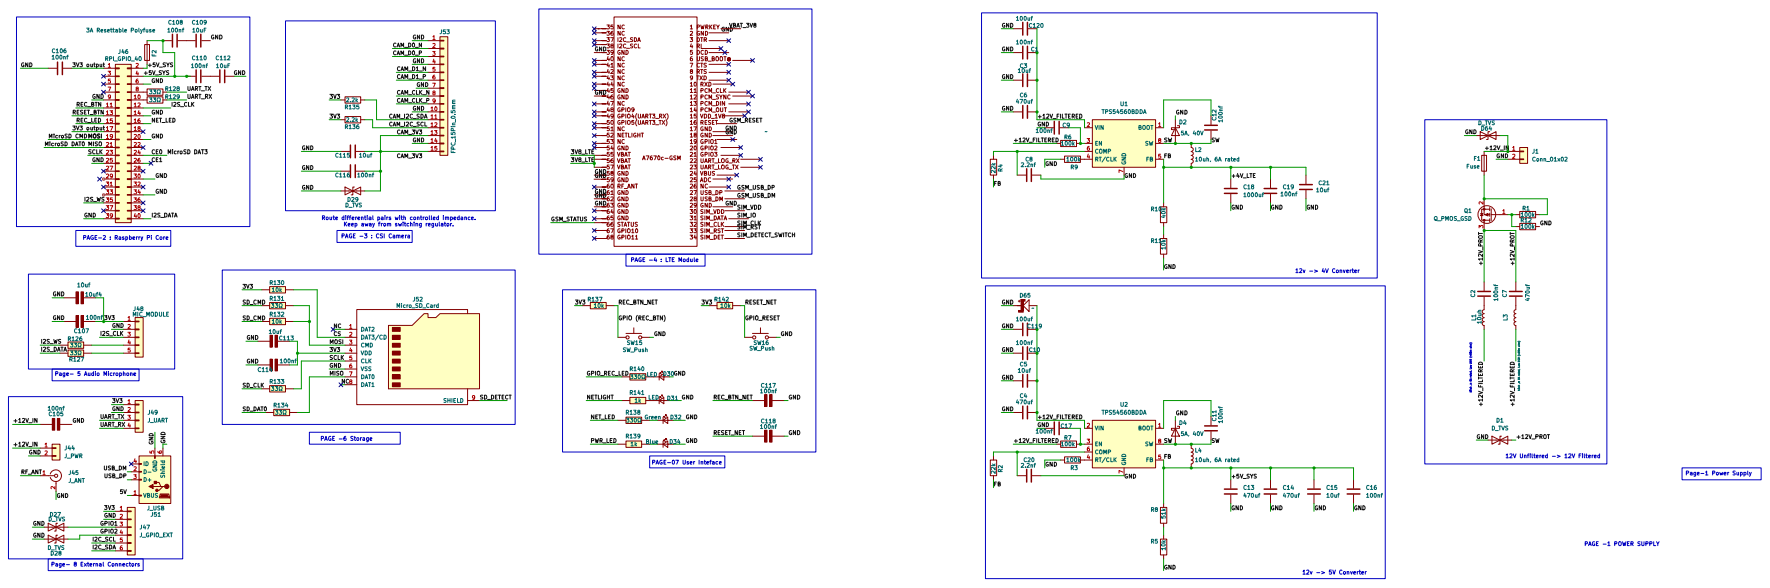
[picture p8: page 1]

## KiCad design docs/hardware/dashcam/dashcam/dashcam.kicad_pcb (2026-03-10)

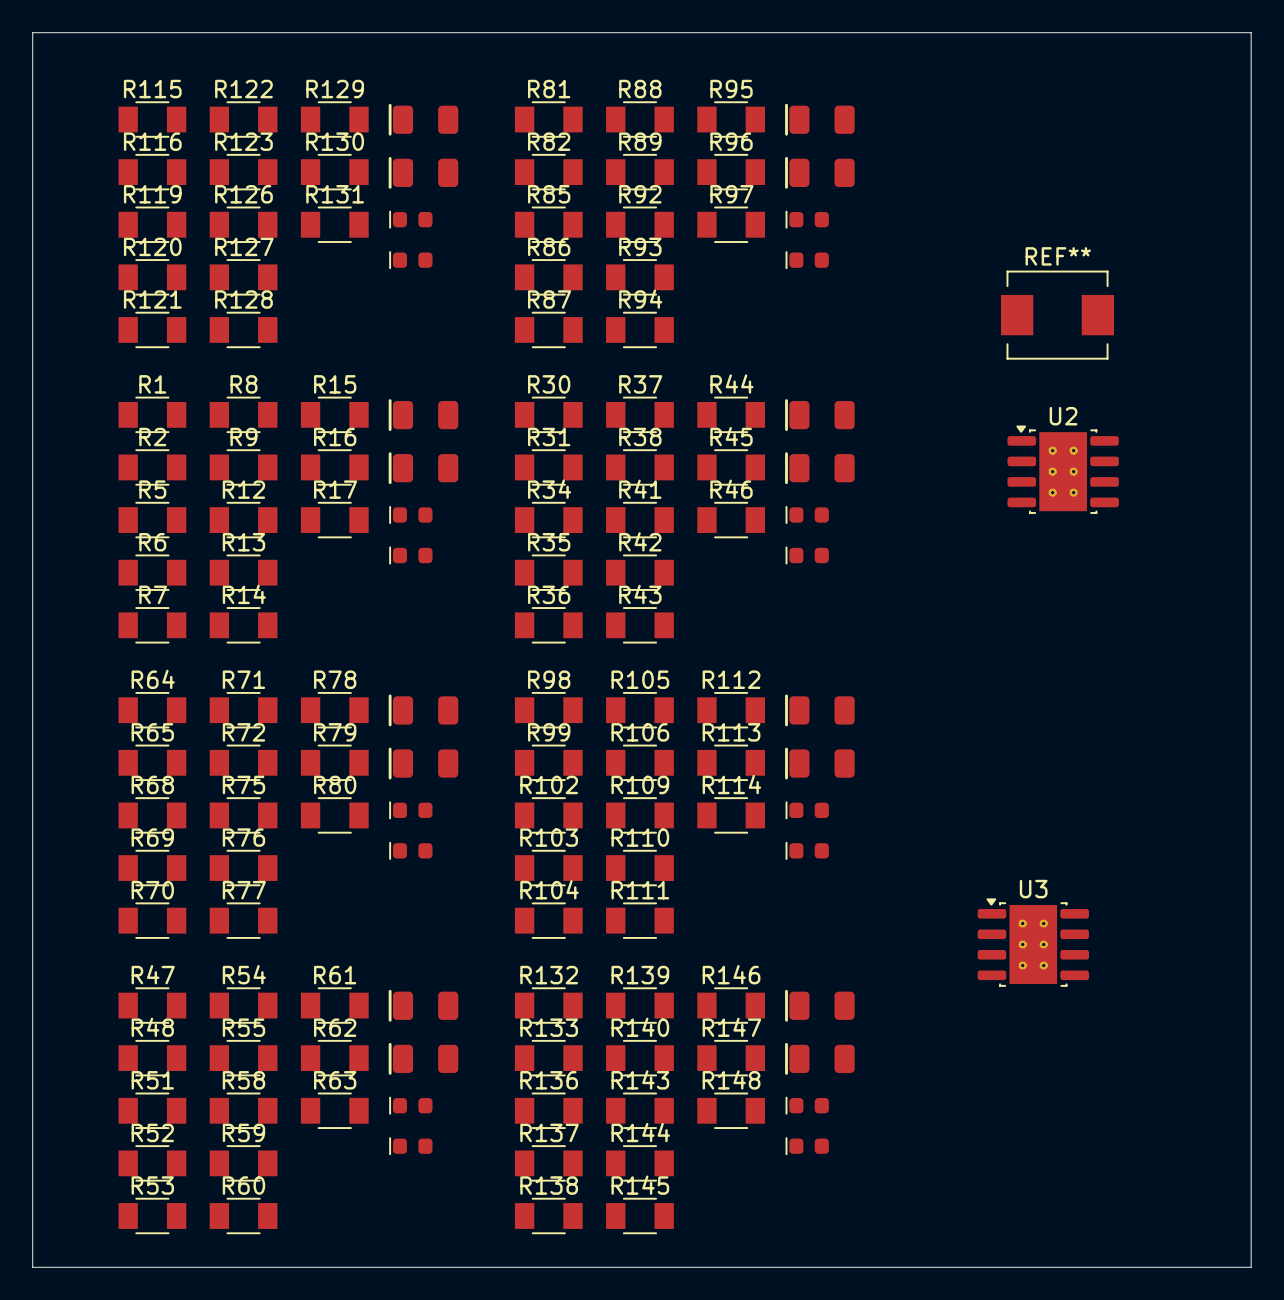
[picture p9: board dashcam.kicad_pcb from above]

Board: 2 copper layers, 75.5 x 76.5 mm, 138 parts (0 on the bottom side), 69 nets, no tracks yet.

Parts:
D4, D5, D20, D21, D31, D32, D42, D43, D53, D54, D64, D65, D75, D76, D86, D87: LED; LED_0603_1608Metric
D6, D22, D33, D44, D55, D66, D77, D88: Green; LED_1206_3216Metric_Green
D7, D23, D34, D45, D56, D67, D78, D89: Blue; LED_1206_3216Metric_Blue
R1, R2, R6, R8, R9, R30, R31, R35, R37, R38, R47, R48, R52, R54, R55, R64, R65, R69, R71, R72, R81, R82, R86, R88, R89, R98, R99, R103, R105, R106, R115, R116, R120, R122, R123, R132, R133, R137, R139, R140: 33Ω; R_1206
R5, R7, R12, R17, R34, R36, R41, R46, R51, R53, R58, R63, R68, R70, R75, R80, R85, R87, R92, R97, R102, R104, R109, R114, R119, R121, R126, R131, R136, R138, R143, R148: 10k; R_1206
R13, R15, R42, R44, R59, R61, R76, R78, R93, R95, R110, R112, R127, R129, R144, R146: 330Ω; R_1206
R14, R16, R43, R45, R60, R62, R77, R79, R94, R96, R111, R113, R128, R130, R145, R147: 1k; R_1206
U2, U3: TPS54560BDDA; Texas_R-PDSO-G8_EP2.95x4.9mm_Mask2.4x3.1mm_ThermalVias

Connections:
/00_System_Overview.kicad_sch/3V3: R5.1, R12.1, R17.1
/00_System_Overview.kicad_sch/GND: D4.2 (A), D5.2 (A), D6.2 (A), D7.2 (A)
/00_System_Overview.kicad_sch/MOSI: R6.2, R7.2
/00_System_Overview.kicad_sch/SD_CMD: R6.1, R7.1
/01_Power_Supply.kicad_sch/+4V_LTE: U2.5 (FB), U3.5 (FB)
/01_Power_Supply.kicad_sch/+12V_FILTERED: U2.2 (VIN), U3.2 (VIN)
/01_Power_Supply.kicad_sch/GND: U2.7 (GND), U2.9 (GND)
/01_Power_Supply.kicad_sch/SW: U2.8 (SW), U3.8 (SW)
/02_Raspberry_Pi_Core.kicad_sch/3V3: R34.1, R41.1, R46.1
/02_Raspberry_Pi_Core.kicad_sch/GND: D20.2 (A), D21.2 (A), D22.2 (A), D23.2 (A)
/02_Raspberry_Pi_Core.kicad_sch/MOSI: R35.2, R36.2
/02_Raspberry_Pi_Core.kicad_sch/SD_CMD: R35.1, R36.1
/03_CSI_Camera_Interface.kicad_sch/3V3: R51.1, R58.1, R63.1
/03_CSI_Camera_Interface.kicad_sch/GND: D31.2 (A), D32.2 (A), D33.2 (A), D34.2 (A)
/03_CSI_Camera_Interface.kicad_sch/MOSI: R52.2, R53.2
/03_CSI_Camera_Interface.kicad_sch/SD_CMD: R52.1, R53.1
/04_LTE_Module.kicad_sch/3V3: R68.1, R75.1, R80.1
/04_LTE_Module.kicad_sch/GND: D42.2 (A), D43.2 (A), D44.2 (A), D45.2 (A)
/04_LTE_Module.kicad_sch/MOSI: R69.2, R70.2
/04_LTE_Module.kicad_sch/SD_CMD: R69.1, R70.1
/05_Audio_Microphone.kicad_sch/3V3: R85.1, R92.1, R97.1
/05_Audio_Microphone.kicad_sch/GND: D53.2 (A), D54.2 (A), D55.2 (A), D56.2 (A)
/05_Audio_Microphone.kicad_sch/MOSI: R86.2, R87.2
/05_Audio_Microphone.kicad_sch/SD_CMD: R86.1, R87.1
/06_Storage.kicad_sch/3V3: R102.1, R109.1, R114.1
/06_Storage.kicad_sch/GND: D64.2 (A), D65.2 (A), D66.2 (A), D67.2 (A)
/06_Storage.kicad_sch/MOSI: R103.2, R104.2
/06_Storage.kicad_sch/SD_CMD: R103.1, R104.1
/07_User_Interface.kicad_sch/3V3: R119.1, R126.1, R131.1
/07_User_Interface.kicad_sch/GND: D75.2 (A), D76.2 (A), D77.2 (A), D78.2 (A)
/07_User_Interface.kicad_sch/MOSI: R120.2, R121.2
/07_User_Interface.kicad_sch/SD_CMD: R120.1, R121.1
/08_External_Connectors.kicad_sch/3V3: R136.1, R143.1, R148.1
/08_External_Connectors.kicad_sch/GND: D86.2 (A), D87.2 (A), D88.2 (A), D89.2 (A)
/08_External_Connectors.kicad_sch/MOSI: R137.2, R138.2
/08_External_Connectors.kicad_sch/SD_CMD: R137.1, R138.1
unnamed: U3.7 (GND), U3.9 (GND)
unnamed: D4.1 (K), R15.2
unnamed: D5.1 (K), R16.2
unnamed: D6.1 (K), R13.2
unnamed: D7.1 (K), R14.2
unnamed: D20.1 (K), R44.2
unnamed: D21.1 (K), R45.2
unnamed: D22.1 (K), R42.2
unnamed: D23.1 (K), R43.2
unnamed: D31.1 (K), R61.2
unnamed: D32.1 (K), R62.2
unnamed: D33.1 (K), R59.2
unnamed: D34.1 (K), R60.2
unnamed: D42.1 (K), R78.2
unnamed: D43.1 (K), R79.2
unnamed: D44.1 (K), R76.2
unnamed: D45.1 (K), R77.2
unnamed: D53.1 (K), R95.2
unnamed: D54.1 (K), R96.2
unnamed: D55.1 (K), R93.2
unnamed: D56.1 (K), R94.2
unnamed: D64.1 (K), R112.2
unnamed: D65.1 (K), R113.2
unnamed: D66.1 (K), R110.2
unnamed: D67.1 (K), R111.2
unnamed: D75.1 (K), R129.2
unnamed: D76.1 (K), R130.2
unnamed: D77.1 (K), R127.2
unnamed: D78.1 (K), R128.2
unnamed: D86.1 (K), R146.2
unnamed: D87.1 (K), R147.2
unnamed: D88.1 (K), R144.2
unnamed: D89.1 (K), R145.2

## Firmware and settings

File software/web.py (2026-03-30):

#!/usr/bin/env python3
"""
DriveEasy Eye - Web Dashboard
Runs on port 5000. Open http://PI_IP:5000 on any phone/browser.

Shows:
  - Live dashcam video (WebRTC embed)
  - Live location on OpenStreetMap (free, no API key)
  - Live telemetry: speed, GPS coords, session stats
  - Record button (triggers webrtc_ai_sender.py recording)
  - Trip trail on map

Run alongside main dashcam:
  python3 web.py

Install Flask if needed:
  pip install flask --break-system-packages
"""

from flask import Flask, jsonify, send_file, Response
import json
import os
import io
from datetime import datetime

app  = Flask(__name__)

LOCATION_FILE    = "/home/driveeasy/ai_dashcam/location.json"
SIGNALING_SERVER = "wss://driveeasy-eye-signaling-904892438797.us-central1.run.app/"
DEVICE_ID        = "AICAM1"
RECORD_PORT      = 8080


# ==========================
# API ENDPOINTS
# ==========================

@app.route("/api/location")
def api_location():
    try:
        with open(LOCATION_FILE, "r") as f:
            data = json.load(f)
        return jsonify(data)
    except Exception:
        return jsonify({
            "lat": 17.3850, "lon": 78.4867,
            "speed": 0, "valid": False,
            "time": datetime.now().strftime("%Y-%m-%d %H:%M:%S")
        })


@app.route("/api/record")
def api_record():
    """Proxy to dashcam recorder."""
    import urllib.request
    try:
        res = urllib.request.urlopen(
            f"http://localhost:{RECORD_PORT}/record", timeout=2
        )
        return jsonify({"ok": True, "msg": res.read().decode()})
    except Exception as e:
        return jsonify({"ok": False, "msg": str(e)})


@app.route("/api/status")
def api_status():
    try:
        import urllib.request
        res  = urllib.request.urlopen(
            f"http://localhost:{RECORD_PORT}/status", timeout=2
        )
        data = json.loads(res.read().decode())
        return jsonify(data)
    except Exception:
        return jsonify({"recording": False})


# ==========================
# MAIN DASHBOARD PAGE
# ==========================

@app.route("/")
def index():
    html = f"""<!DOCTYPE html>
<html lang="en">
<head>
<meta charset="UTF-8">
<meta name="viewport" content="width=device-width, initial-scale=1.0">
<title>DriveEasy Eye — Live Dashboard</title>
<link rel="stylesheet" href="https://unpkg.com/leaflet@1.9.4/dist/leaflet.css"/>
<script src="https://unpkg.com/leaflet@1.9.4/dist/leaflet.js"></script>
<style>
  :root {{
    --blue:   #0A84FF;
    --cyan:   #00D4FF;
    --green:  #30D158;
    --red:    #FF453A;
    --amber:  #FFD60A;
    --bg:     #0A0A0F;
    --panel:  #13131A;
    --border: #1E1E2E;
    --text:   #E8E8F0;
    --muted:  #6B6B80;
  }}

  * {{ margin: 0; padding: 0; box-sizing: border-box; }}

  body {{
    background: var(--bg);
    color: var(--text);
    font-family: 'Courier New', monospace;
    height: 100vh;
    overflow: hidden;
    display: flex;
    flex-direction: column;
  }}

  /* ── TOP BAR ── */
  .topbar {{
    background: var(--panel);
    border-bottom: 1px solid var(--border);
    padding: 10px 20px;
    display: flex;
    align-items: center;
    justify-content: space-between;
    flex-shrink: 0;
    height: 56px;
  }}

  .brand {{
    display: flex;
    align-items: center;
    gap: 12px;
  }}

  /* Programmatic D logo in CSS */
  .logo-d {{
    width: 36px;
    height: 36px;
    position: relative;
    flex-shrink: 0;
  }}
  .logo-d svg {{ width: 100%; height: 100%; }}

  .brand-text {{
    font-size: 16px;
    font-weight: bold;
    color: var(--cyan);
    letter-spacing: 1px;
  }}
  .brand-sub {{
    font-size: 10px;
    color: var(--muted);
    letter-spacing: 2px;
  }}

  .topbar-right {{
    display: flex;
    align-items: center;
    gap: 16px;
  }}

  .live-badge {{
    display: flex;
    align-items: center;
    gap: 6px;
    background: rgba(48, 209, 88, 0.15);
    border: 1px solid var(--green);
    border-radius: 20px;
    padding: 4px 12px;
    font-size: 11px;
    color: var(--green);
    font-weight: bold;
    letter-spacing: 1px;
  }}
  .live-dot {{
    width: 7px; height: 7px;
    background: var(--green);
    border-radius: 50%;
    animation: pulse 1.4s ease-in-out infinite;
  }}
  @keyframes pulse {{
    0%, 100% {{ opacity: 1; transform: scale(1); }}
    50%       {{ opacity: 0.5; transform: scale(0.8); }}
  }}

  .time-display {{
    font-size: 13px;
    color: var(--cyan);
    letter-spacing: 1px;
  }}

  /* ── MAIN LAYOUT ── */
  .main {{
    display: grid;
    grid-template-columns: 1fr 380px;
    grid-template-rows: 1fr 120px;
    gap: 8px;
    padding: 8px;
    flex: 1;
    overflow: hidden;
    min-height: 0;
  }}

  /* ── VIDEO PANEL ── */
  .video-panel {{
    grid-row: 1 / 2;
    grid-column: 1 / 2;
    background: #000;
    border: 1px solid var(--border);
    border-radius: 10px;
    overflow: hidden;
    position: relative;
    display: flex;
    align-items: center;
    justify-content: center;
  }}

  .video-panel iframe {{
    width: 100%;
    height: 100%;
    border: none;
  }}

  .video-label {{
    position: absolute;
    top: 10px;
    right: 12px;
    background: rgba(0,0,0,0.7);
    color: var(--cyan);
    font-size: 10px;
    letter-spacing: 2px;
    padding: 3px 8px;
    border-radius: 4px;
    border: 1px solid var(--border);
  }}

  /* ── MAP PANEL ── */
  .map-panel {{
    grid-row: 1 / 2;
    grid-column: 2 / 3;
    border: 1px solid var(--border);
    border-radius: 10px;
    overflow: hidden;
    position: relative;
    display: flex;
    flex-direction: column;
  }}

  .map-header {{
    background: var(--panel);
    padding: 8px 14px;
    font-size: 11px;
    color: var(--cyan);
    letter-spacing: 2px;
    display: flex;
    align-items: center;
    justify-content: space-between;
    border-bottom: 1px solid var(--border);
    flex-shrink: 0;
  }}

  .gps-indicator {{
    display: flex;
    align-items: center;
    gap: 5px;
    font-size: 10px;
  }}
  .gps-dot {{
    width: 6px; height: 6px;
    border-radius: 50%;
    background: var(--muted);
    transition: background 0.4s;
  }}
  .gps-dot.active {{ background: var(--green); }}

  #map {{
    flex: 1;
    min-height: 0;
  }}

  .map-coords {{
    background: var(--panel);
    padding: 6px 14px;
    font-size: 10px;
    color: var(--muted);
    display: flex;
    justify-content: space-between;
    border-top: 1px solid var(--border);
    flex-shrink: 0;
  }}

  /* ── TELEMETRY BAR ── */
  .telemetry-bar {{
    grid-row: 2 / 3;
    grid-column: 1 / 3;
    background: var(--panel);
    border: 1px solid var(--border);
    border-radius: 10px;
    display: flex;
    align-items: center;
    padding: 0 20px;
    gap: 0;
    overflow: hidden;
  }}

  .tele-item {{
    flex: 1;
    display: flex;
    flex-direction: column;
    align-items: center;
    justify-content: center;
    padding: 8px 6px;
    border-right: 1px solid var(--border);
    min-width: 0;
  }}
  .tele-item:last-child {{ border-right: none; }}

  .tele-label {{
    font-size: 9px;
    color: var(--muted);
    letter-spacing: 2px;
    text-transform: uppercase;
    margin-bottom: 4px;
  }}

  .tele-value {{
    font-size: 20px;
    font-weight: bold;
    color: var(--text);
    letter-spacing: 1px;
    line-height: 1;
  }}

  .tele-value.speed  {{ color: var(--cyan);  }}
  .tele-value.green  {{ color: var(--green); }}
  .tele-value.amber  {{ color: var(--amber); }}
  .tele-value.red    {{ color: var(--red);   }}
  .tele-value.blue   {{ color: var(--blue);  }}

  .tele-unit {{
    font-size: 9px;
    color: var(--muted);
    margin-top: 2px;
  }}

  /* Record button */
  .rec-btn {{
    background: rgba(255,69,58,0.15);
    border: 1px solid var(--red);
    color: var(--red);
    border-radius: 8px;
    padding: 8px 18px;
    font-family: 'Courier New', monospace;
    font-size: 12px;
    font-weight: bold;
    letter-spacing: 2px;
    cursor: pointer;
    display: flex;
    align-items: center;
    gap: 8px;
    transition: all 0.2s;
    white-space: nowrap;
  }}
  .rec-btn:hover {{
    background: rgba(255,69,58,0.3);
  }}
  .rec-btn.recording {{
    background: rgba(255,69,58,0.4);
    animation: rec-flash 1s ease-in-out infinite;
  }}
  @keyframes rec-flash {{
    0%, 100% {{ border-color: var(--red); }}
    50%       {{ border-color: transparent; }}
  }}
  .rec-circle {{
    width: 10px; height: 10px;
    background: var(--red);
    border-radius: 50%;
  }}

  /* Map custom styles */
  .leaflet-container {{
    background: #1a1a2e !important;
    font-family: 'Courier New', monospace;
  }}
  .speed-popup {{
    background: var(--panel);
    color: var(--cyan);
    border: 1px solid var(--blue);
    border-radius: 6px;
    padding: 4px 10px;
    font-size: 12px;
    font-family: monospace;
  }}
</style>
</head>
<body>

<!-- ── TOP BAR ── -->
<div class="topbar">
  <div class="brand">
    <!-- DriveEasy D logo in SVG — always renders, no file needed -->
    <div class="logo-d">
      <svg viewBox="0 0 100 100" xmlns="http://www.w3.org/2000/svg">
        <path d="M15 10 Q75 10 85 50 Q75 90 15 90 Z" fill="none" stroke="#0064C8" stroke-width="9" stroke-linejoin="round"/>
        <line x1="14" y1="25" x2="65" y2="25" stroke="#0064C8" stroke-width="9" stroke-linecap="round"/>
        <line x1="14" y1="40" x2="73" y2="40" stroke="#0064C8" stroke-width="9" stroke-linecap="round"/>
        <line x1="14" y1="55" x2="76" y2="55" stroke="#0064C8" stroke-width="9" stroke-linecap="round"/>
        <line x1="14" y1="70" x2="72" y2="70" stroke="#0064C8" stroke-width="9" stroke-linecap="round"/>
        <line x1="14" y1="85" x2="62" y2="85" stroke="#0064C8" stroke-width="9" stroke-linecap="round"/>
      </svg>
    </div>
    <div>
      <div class="brand-text">DriveEasy Eye</div>
      <div class="brand-sub">AI DASHCAM · {DEVICE_ID}</div>
    </div>
  </div>

  <div class="topbar-right">
    <div class="live-badge">
      <div class="live-dot"></div>
      LIVE
    </div>
    <div class="time-display" id="clock">--:--:--</div>
  </div>
</div>

<!-- ── MAIN CONTENT ── -->
<div class="main">

  <!-- Video -->
  <div class="video-panel">
    <iframe
      src="https://driveeasy-eye-web-904892438797.us-central1.run.app"
      allow="camera; microphone; autoplay"
      allowfullscreen>
    </iframe>
    <div class="video-label">AICAM1 · 1280×720</div>
  </div>

  <!-- Map -->
  <div class="map-panel">
    <div class="map-header">
      <span>LIVE LOCATION</span>
      <div class="gps-indicator">
        <div class="gps-dot" id="gps-dot"></div>
        <span id="gps-status">LOCATING...</span>
      </div>
    </div>
    <div id="map"></div>
    <div class="map-coords">
      <span id="coord-lat">Lat: --</span>
      <span id="coord-lon">Lon: --</span>
      <span id="coord-time">--</span>
    </div>
  </div>

  <!-- Telemetry bar -->
  <div class="telemetry-bar">

    <div class="tele-item">
      <div class="tele-label">SPEED</div>
      <div class="tele-value speed" id="t-speed">--</div>
      <div class="tele-unit">km/h</div>
    </div>

    <div class="tele-item">
      <div class="tele-label">LATITUDE</div>
      <div class="tele-value blue" id="t-lat" style="font-size:14px">--</div>
      <div class="tele-unit">degrees</div>
    </div>

    <div class="tele-item">
      <div class="tele-label">LONGITUDE</div>
      <div class="tele-value blue" id="t-lon" style="font-size:14px">--</div>
      <div class="tele-unit">degrees</div>
    </div>

    <div class="tele-item">
      <div class="tele-label">GPS FIX</div>
      <div class="tele-value green" id="t-fix">--</div>
      <div class="tele-unit">status</div>
    </div>

    <div class="tele-item">
      <div class="tele-label">LAST UPDATE</div>
      <div class="tele-value" id="t-time" style="font-size:12px">--</div>
      <div class="tele-unit">timestamp</div>
    </div>

    <div class="tele-item">
      <div class="tele-label">TRAIL PTS</div>
      <div class="tele-value amber" id="t-trail">0</div>
      <div class="tele-unit">points</div>
    </div>

    <div class="tele-item" style="flex: 0 0 auto; padding: 0 20px;">
      <button class="rec-btn" id="rec-btn" onclick="toggleRecord()">
        <div class="rec-circle"></div>
        <span id="rec-label">RECORD</span>
      </button>
    </div>

  </div>
</div>

<script>
// ── CLOCK ──
function updateClock() {{
  document.getElementById('clock').textContent =
    new Date().toLocaleTimeString('en-IN', {{hour12: false}});
}}
updateClock();
setInterval(updateClock, 1000);

// ── MAP SETUP ──
const map = L.map('map', {{
  zoomControl: true,
  attributionControl: false
}}).setView([17.3850, 78.4867], 15);

// Dark OpenStreetMap tile layer — free, no API key
L.tileLayer('https://{{s}}.basemaps.cartocdn.com/dark_all/{{z}}/{{x}}/{{y}}{{r}}.png', {{
  subdomains: 'abcd',
  maxZoom: 19
}}).addTo(map);

// Custom marker icon
const markerIcon = L.divIcon({{
  className: '',
  html: `<div style="
    width:18px; height:18px;
    background:#00D4FF;
    border:3px solid #fff;
    border-radius:50%;
    box-shadow:0 0 12px #00D4FF;
  "></div>`,
  iconSize:   [18, 18],
  iconAnchor: [9, 9]
}});

const marker = L.marker([17.3850, 78.4867], {{icon: markerIcon}}).addTo(map);
marker.bindPopup('<div class="speed-popup">DriveEasy Eye · AICAM1</div>');

// Trail polyline
const trail = L.polyline([], {{
  color:   '#00D4FF',
  weight:  3,
  opacity: 0.8
}}).addTo(map);

let trailCount  = 0;
let isRecording = false;

// ── LOCATION POLLING ──
async function pollLocation() {{
  try {{
    const r    = await fetch('/api/location');
    const data = await r.json();

    const lat = parseFloat(data.lat);
    const lon = parseFloat(data.lon);
    const spd = parseFloat(data.speed) || 0;
    const valid = data.valid;

    // Update marker + trail
    const ll = [lat, lon];
    marker.setLatLng(ll);
    trail.addLatLng(ll);
    trailCount++;
    map.panTo(ll);

    // GPS indicator
    const dot = document.getElementById('gps-dot');
    const sta = document.getElementById('gps-status');
    if (valid) {{
      dot.classList.add('active');
      sta.textContent = 'GPS FIX';
    }} else {{
      dot.classList.remove('active');
      sta.textContent = 'NO FIX';
    }}

    // Telemetry values
    document.getElementById('t-speed').textContent = spd.toFixed(1);
    document.getElementById('t-lat').textContent   = lat.toFixed(5);
    document.getElementById('t-lon').textContent   = lon.toFixed(5);
    document.getElementById('t-fix').textContent   = valid ? 'LOCKED' : 'SEARCH';
    document.getElementById('t-fix').className     = 'tele-value ' + (valid ? 'green' : 'amber');
    document.getElementById('t-time').textContent  = data.time || '--';
    document.getElementById('t-trail').textContent = trailCount;

    // Coords bar
    document.getElementById('coord-lat').textContent  = 'Lat: ' + lat.toFixed(6);
    document.getElementById('coord-lon').textContent  = 'Lon: ' + lon.toFixed(6);
    document.getElementById('coord-time').textContent = data.time || '--';

    // Speed color
    const sv = document.getElementById('t-speed');
    sv.className = 'tele-value speed';
    if (spd > 80) sv.className = 'tele-value red';
    else if (spd > 50) sv.className = 'tele-value amber';

  }} catch (e) {{
    console.log('Location poll error:', e);
  }}
}}

pollLocation();
setInterval(pollLocation, 2000);

// ── RECORD TOGGLE ──
async function toggleRecord() {{
  const btn   = document.getElementById('rec-btn');
  const label = document.getElementById('rec-label');
  try {{
    const r    = await fetch('/api/record');
    const data = await r.json();
    isRecording = !isRecording;
    if (isRecording) {{
      btn.classList.add('recording');
      label.textContent = 'STOP REC';
    }} else {{
      btn.classList.remove('recording');
      label.textContent = 'RECORD';
    }}
  }} catch (e) {{
    console.log('Record error:', e);
  }}
}}

// ── CLEAR TRAIL ──
function clearTrail() {{
  trail.setLatLngs([]);
  trailCount = 0;
  document.getElementById('t-trail').textContent = '0';
}}

// Right-click map to clear trail
map.on('contextmenu', clearTrail);
</script>
</body>
</html>"""
    return html


if __name__ == "__main__":
    print("=" * 50)
    print("DriveEasy Eye Web Dashboard")
    print("Open on phone: http://PI_IP_ADDRESS:5000")
    print("=" * 50)
    app.run(host="0.0.0.0", port=5000, debug=False)

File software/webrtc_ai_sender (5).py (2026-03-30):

#!/usr/bin/env python3
"""
DriveEasy Eye - Advanced AI Smart Dashcam v4.1

SETUP:
  export GEMINI_API_KEY="your_key"
  python3 webrtc_ai_sender.py

v4.1 Changes (header upgrade only, nothing else changed):
  * Top-right of header now shows:
      Line 1: lat/lon in small text
      Line 2: City, State, India  (reverse geocoded via OSM Nominatim - FREE)
  * Reverse geocoding runs in background thread every 30 sec — never blocks video
  * Falls back to raw coords if no internet / GPS not fixed
  * Logo generated programmatically — no file needed
  * GPS writes location.json every 2 sec for web.py map
"""

import asyncio
import cv2
import numpy as np
from picamera2 import Picamera2
import json
import websockets
from aiortc import RTCPeerConnection, RTCSessionDescription, VideoStreamTrack
from aiortc import RTCConfiguration, RTCIceServer
from av import VideoFrame
import time
from datetime import datetime
import os
import threading
import re
import collections
import urllib.request
import urllib.parse
from http.server import BaseHTTPRequestHandler, HTTPServer
import google.generativeai as genai

# ── Constants ──────────────────────────────────────────────────────────────────
SIGNALING_SERVER = "wss://driveeasy-eye-signaling-904892438797.us-central1.run.app/"
DEVICE_ID        = "AICAM1"
EVENT_FOLDER     = "events"
HTTP_PORT        = 8080
LOCATION_FILE    = "/home/driveeasy/ai_dashcam/location.json"

FOCAL_LENGTH     = 700

KNOWN_HEIGHTS = {
    "person":    1.7,
    "car":       1.5,
    "truck":     3.5,
    "bus":       3.2,
    "motorbike": 1.2,
}

VEHICLE_LABELS = {"car", "truck", "bus", "motorbike"}

if not os.path.exists(EVENT_FOLDER):
    os.makedirs(EVENT_FOLDER)


# ==========================
# LOGO GENERATOR
# ==========================

def generate_logo(height=40):
    """Generates DriveEasy D logo programmatically. No file needed."""
    size  = height
    img   = np.zeros((size, size, 3), dtype=np.uint8)
    cx    = size // 2
    cy    = size // 2
    blue  = (200, 100, 0)
    thick = max(2, size // 14)

    cv2.ellipse(img, (cx - size // 10, cy),
                (size // 2 - thick, size // 2 - thick),
                0, -75, 75, blue, thick)

    line_xs = size // 6
    line_xe = cx + size // 8
    gaps    = 5
    for i in range(gaps):
        y = int(thick + i * (size - 2 * thick) / (gaps - 1))
        cv2.line(img, (line_xs, y), (line_xe, y), blue, thick)
        cv2.circle(img, (line_xs, y), thick // 2, blue, -1)
        cv2.circle(img, (line_xe, y), thick // 2, blue, -1)

    gray    = cv2.cvtColor(img, cv2.COLOR_BGR2GRAY)
    _, mask = cv2.threshold(gray, 10, 255, cv2.THRESH_BINARY)
    print(f"Logo generated: {size}x{size}px")
    return img, mask


def overlay_logo(frame, logo, mask, x_offset=5, y_offset=5):
    if logo is None:
        return
    lh, lw = logo.shape[:2]
    roi = frame[y_offset:y_offset + lh, x_offset:x_offset + lw]
    if roi.shape[:2] != (lh, lw):
        return
    logo_area = cv2.bitwise_and(logo, logo, mask=mask)
    bg_area   = cv2.bitwise_and(roi,  roi,  mask=cv2.bitwise_not(mask))
    frame[y_offset:y_offset + lh, x_offset:x_offset + lw] = cv2.add(logo_area, bg_area)


# ==========================
# REVERSE GEOCODER (FREE - OSM Nominatim)
# ==========================

class ReverseGeocoder:
    """
    Converts GPS lat/lon to city, state, country using
    OpenStreetMap Nominatim API — completely FREE, no key needed.
    Runs in background thread every 30 seconds.
    Displays in header top-right:
      Line 1: lat, lon (small)
      Line 2: City, State, India
    """

    def __init__(self):
        self.city    = ""
        self.state   = ""
        self.country = "India"
        self.lat     = None
        self.lon     = None
        self._lock   = threading.Lock()
        self._last_geocode_time = 0
        self._geocode_interval  = 30  # seconds between API calls
        print("Reverse geocoder ready (OpenStreetMap Nominatim - FREE)")

    def update_coords(self, lat, lon):
        """Call this whenever new GPS coords arrive."""
        with self._lock:
            self.lat = lat
            self.lon = lon

        # Only geocode every 30 seconds (don't hammer OSM)
        if time.time() - self._last_geocode_time > self._geocode_interval:
            self._last_geocode_time = time.time()
            threading.Thread(
                target=self._fetch_location,
                args=(lat, lon),
                daemon=True
            ).start()

    def _fetch_location(self, lat, lon):
        """Background fetch from OSM Nominatim."""
        try:
            url = (
                f"https://nominatim.openstreetmap.org/reverse"
                f"?lat={lat}&lon={lon}&format=json&zoom=10"
            )
            req = urllib.request.Request(url)
            req.add_header("User-Agent", "DriveEasyEye/4.1 dashcam")
            with urllib.request.urlopen(req, timeout=5) as resp:
                data = json.loads(resp.read().decode())

            addr    = data.get("address", {})
            city    = (addr.get("city")
                       or addr.get("town")
                       or addr.get("village")
                       or addr.get("county")
                       or "")
            state   = addr.get("state", "")
            country = addr.get("country", "India")

            # Shorten state name for header space
            state = state.replace("Telangana", "Telangana")
            state = state.replace("Andhra Pradesh", "A.P.")
            state = state.replace("Maharashtra", "Maharashtra")
            state = state.replace("Karnataka", "Karnataka")
            state = state.replace("Tamil Nadu", "T.N.")
            state = state.replace("Uttar Pradesh", "U.P.")
            state = state.replace("Madhya Pradesh", "M.P.")

            with self._lock:
                self.city    = city[:18]     # truncate long names
                self.state   = state[:16]
                self.country = "India"

            print(f"Location: {city}, {state}")

        except Exception as e:
            print(f"Geocode error (non-fatal): {e}")

    def get_header_lines(self):
        """
        Returns two strings for header display:
          line1: "17.3850, 78.4867"
          line2: "Hyderabad, Telangana, India"
        """
        with self._lock:
            lat  = self.lat
            lon  = self.lon
            city = self.city
            st   = self.state
            cntry= self.country

        if lat is None or lon is None:
            return "No GPS Fix", ""

        line1 = f"{lat:.4f}, {lon:.4f}"

        parts = [p for p in [city, st, cntry] if p]
        line2 = ", ".join(parts) if parts else "Locating..."

        return line1, line2


# ==========================
# VOICE ALERT
# ==========================

last_voice_time = 0

def speak(msg):
    global last_voice_time
    if time.time() - last_voice_time > 5:
        os.system(f'espeak "{msg}" &')
        last_voice_time = time.time()
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
